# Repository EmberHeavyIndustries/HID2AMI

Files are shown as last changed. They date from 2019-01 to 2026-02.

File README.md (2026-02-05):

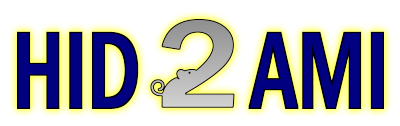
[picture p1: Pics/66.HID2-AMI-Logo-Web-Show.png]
HID2AMI


## ** Preassembled units **: If you are interested in ready-to-go pre-assembled units, a small number of them is available from time to time, assembled by various users/hobbyists. You can look for one on Amibay's thread [link] and check if there is any available on sale (https://www.amibay.com/threads/new-hid2ami-v3-1-0-mousewheel-support-personality-switch-hid-mouse-and-gamepad-to-amiga-adaptor.2451017/) 

|||Email, Contacts & Requests|
| --- | --- | --- |



**HID2AMI** is an **HID mouse to quadrature waveform converter** and **HID Gamepad adapter** for the Amiga (and C64, Atari 7600, AtariST also..) series of boards; it allows ANY modern HID mouse (not limited to PS/2-USB) and almost ANY (*) modern digital/analog Gamepad to be connected and enjoyed with our Amiga computers.

(*) At the moment it has been tested against dozens of different gamepads,  but working for each and every existing Gamepad cannot be guaranteed; nevertheless, if you find a Pad which does not work with HID2AMI, you are encouraged to contact the author and supply him its "HID Report Descriptor" to be investigated.

[HOW TO SUBMIT AN HID DUMP ](https://github.com/EmberHeavyIndustries/HID2AMI/blob/master/Docs/hid.dump.howto.md)

## **ENABLING MOUSEWHEEL SUPPORT**

In order the mousewheel events to be recognized from Amiga side, a proper driver has to be installed on Amiga.

The driver is freely available, and can be downloaded from the FIRMWARE folder on this github
DRIVER

## **REV 3.1 board** 

HID2AMI Rev. 3.1 board (released in February 2025) upgrades previous versions by compacting the size and layout to the tiniest possible, plus adding the capability to switch firmware functions on the fly.

Rev. 3.1.0 comes with the new fromware v4.0.0 which adds the capability to switch among AMIGA - ATARI_ST - C64 behavior, with peculiar features for each.
All V4.x series firmwares will be backward compatible with V2 and V1 boards

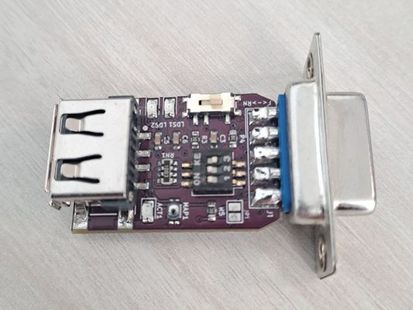
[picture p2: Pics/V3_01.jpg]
Image of HID2AMIV3-01

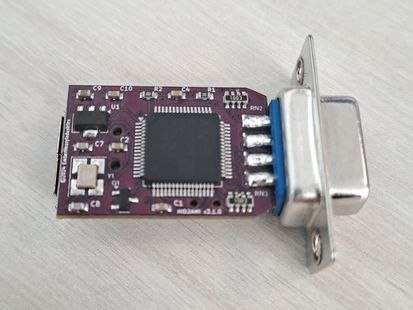
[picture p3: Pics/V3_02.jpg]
Image of HID2AMIV3-02

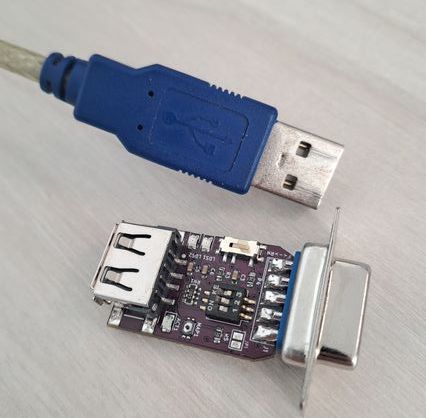
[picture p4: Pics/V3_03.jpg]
Image of HID2AMIV3-03


| Personality | SW1 | SW2  | SW3 | Notes | 
| --- | :---:  | :---:| :---: | --- |
| Amiga | OFF |  OFF | X | Default Classic HID2AMI | 
| Atari ST | ON  |  OFF | X | ST Mouse and Joystick/Joypad |
| C64 | OFF |  ON  | X | C64 Joystick/Joypad with 2nd button |
| CONTROLLER PRIORITY | X  | X  | OFF/ON | J->M->K / K->J->M 	 |

## **Lemaru's shell case (Rev 3.x boards only)** 

Thanks to the talented friend Lemaru, an awesome cover is available for everyone.

You are free to download the stl/step files linked below, and print your own copy of this awesome accessory !

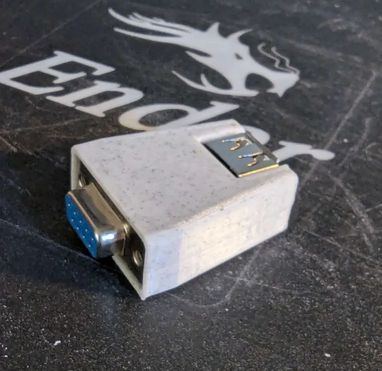
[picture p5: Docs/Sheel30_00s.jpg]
Image of EBOX30-01

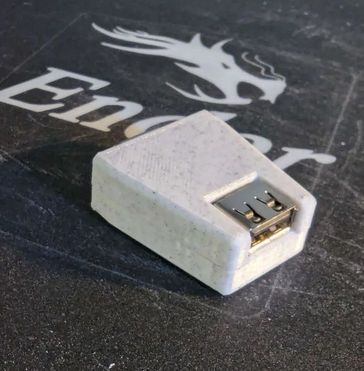
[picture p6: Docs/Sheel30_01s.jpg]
Image of EBOX30-02

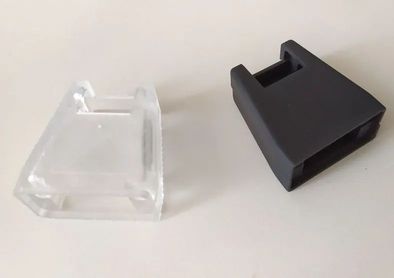
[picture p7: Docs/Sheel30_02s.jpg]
Image of EBOX30-03

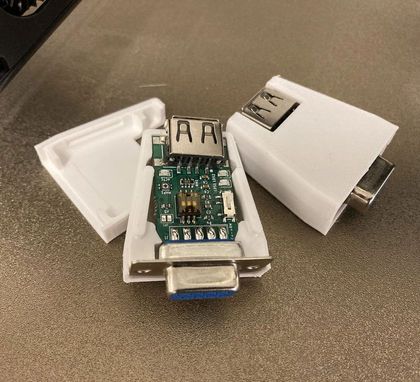
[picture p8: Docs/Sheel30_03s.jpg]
Image of EBOX30-04


[ShellBox30 Top](https://github.com/EmberHeavyIndustries/HID2AMI/blob/master/Docs/HID2AmiV3_Base.stl)

[Shellbox30 Bottom](https://github.com/EmberHeavyIndustries/HID2AMI/blob/master/Docs/HID2AmiV3_Lid.stl)

## **REV 2.0 board** 

HID2AMI Rev. 2.0 board (released in Autumn 2022) upgrades previous versions by adding capability of supporting Mousewheel and CD32 protocols, in a smaller compact shape.

Current firmware v3.0.0 act in the very same way of v1.x.x, with Mousewheel support (CD32 support  will be added in future releases)

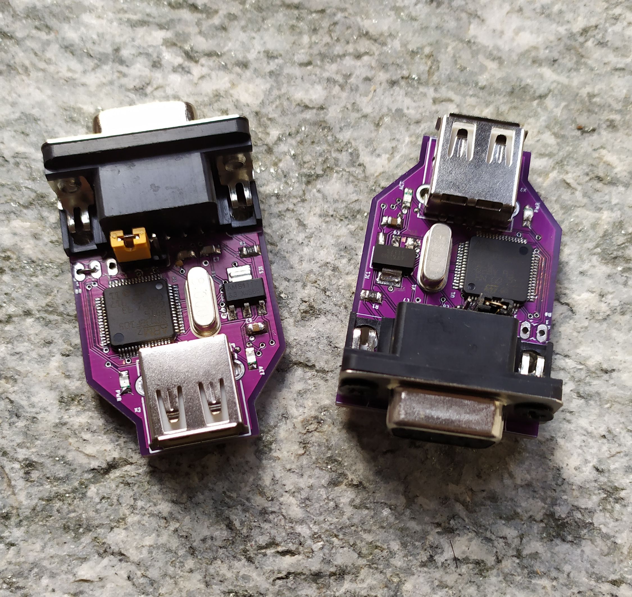
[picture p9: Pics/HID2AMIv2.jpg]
Image of HID2AMI-06
!
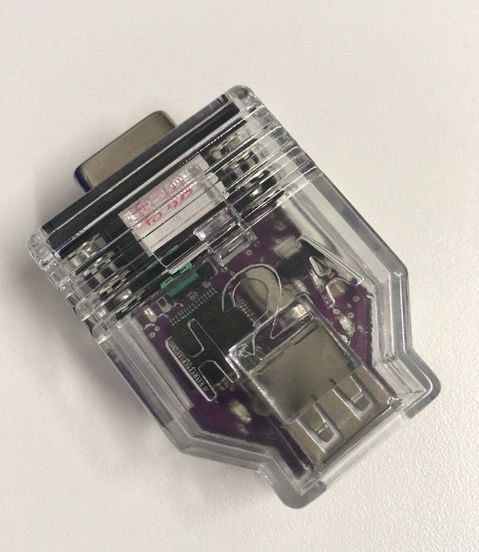
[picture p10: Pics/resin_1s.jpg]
!
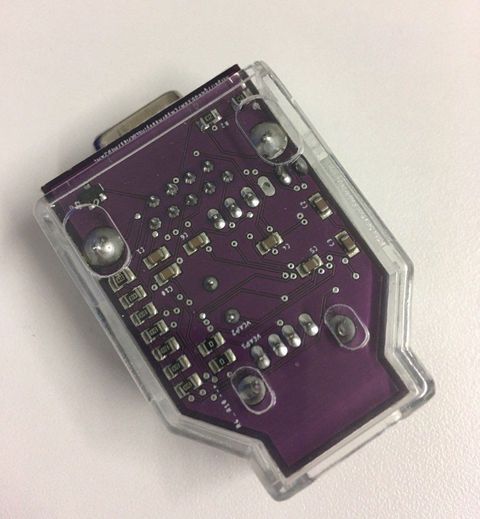
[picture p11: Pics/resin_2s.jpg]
!

(Transparent shellcase images courtesy by IAmAddict)

## **NEW v3.0.0 FIRMWARE WITH MOUSEWHEEL SUPPORT** 

Starting from v3.0.0 firmware, support for mousewheel to ANY adapter hw revision (v1.0, v1.1, V2.0) has been added.

The firmware can be directly flashed on all revisions, and enables native Mousewheel support in v2.0.

In order to enable Mousewheel support on v1.x revisions, a couple of little hacks must be performed on the boards.
The hacks to be performed are: 
- short two adiacent pins of the STM32 microprocessr, by mean of a tiny drop of solder alloy (see pic)
- remove Q2 mosfet and shorten two of the pads (see pic)

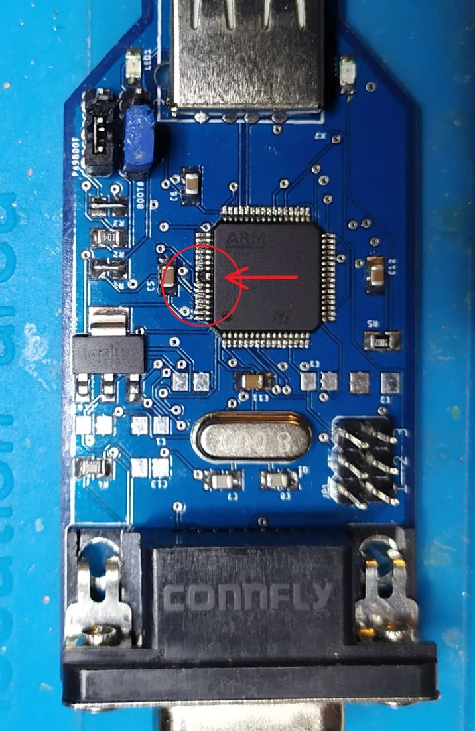
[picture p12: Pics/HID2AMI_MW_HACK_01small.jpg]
HACK01

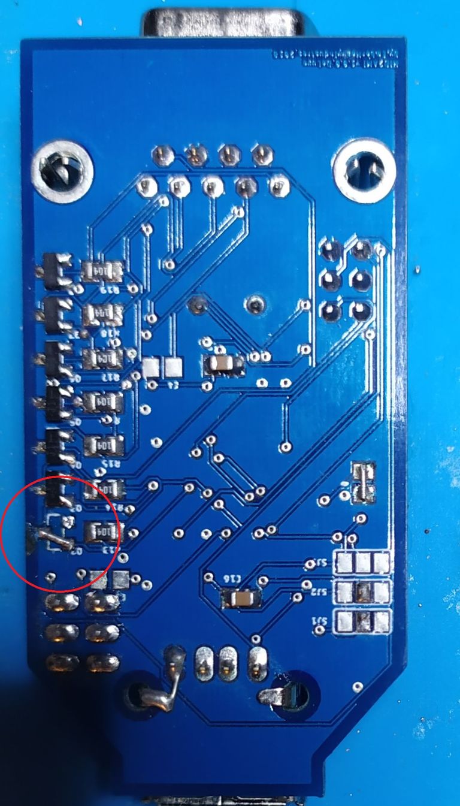
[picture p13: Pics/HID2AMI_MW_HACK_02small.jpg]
HACK02


After the mod, mousewheel works in v1.x all the same way it works in v2.0.
Though the mod is quite trivial, it need a minimal soldering experience.
I cannot be held responsible if anybody damages his board(s) while not properly performing the mod.

In order the mousewheel events to be recognized from Amiga side, a proper driver has to be installed on Amiga.

The driver is freely available, and can be downloaded from the FIRMWARE folder on this github
DRIVER

## **REV 1.1 board** 
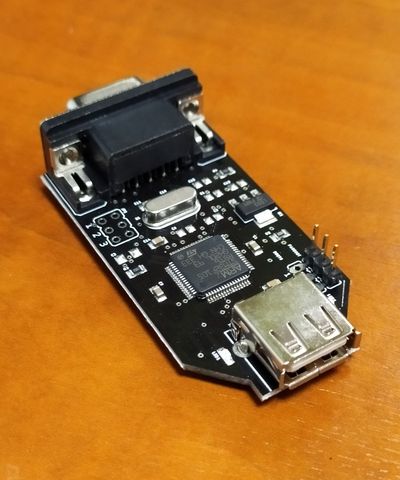
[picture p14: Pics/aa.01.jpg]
Image of HID2AMI-03
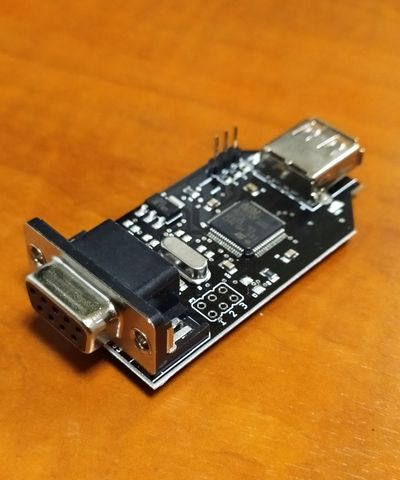
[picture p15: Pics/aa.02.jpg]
Image of HID2AMI-04
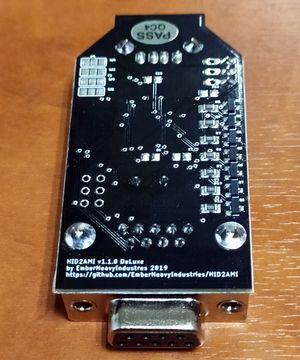
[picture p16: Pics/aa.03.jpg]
Image of HID2AMI-05


## **Ember Heavy Industries's official Open source shell case (Rev 2.x boards only)** 

You are free to download the stl/step files linked below, and print your own copy of this beautiful shell cover !

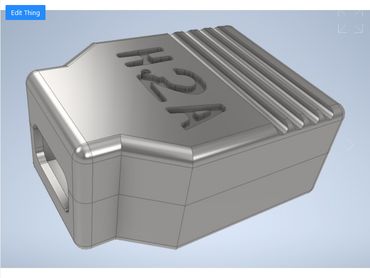
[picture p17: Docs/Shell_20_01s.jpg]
Image of EBOX20-01

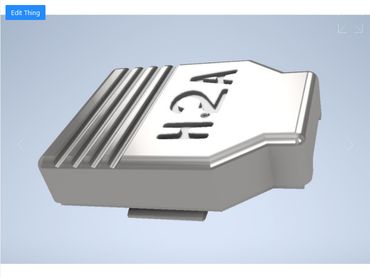
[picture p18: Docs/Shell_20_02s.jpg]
Image of EBOX20-02

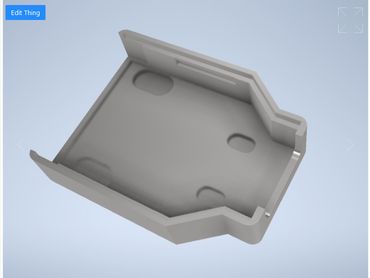
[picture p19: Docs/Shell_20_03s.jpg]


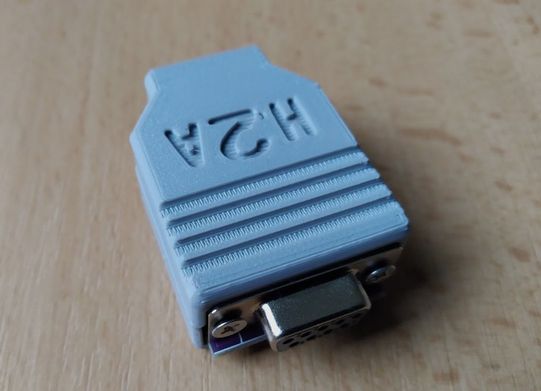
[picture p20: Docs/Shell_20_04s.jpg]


(Sample 3D print by Solaris104)

Image of EBOX20-04
Image of EBOX20-05
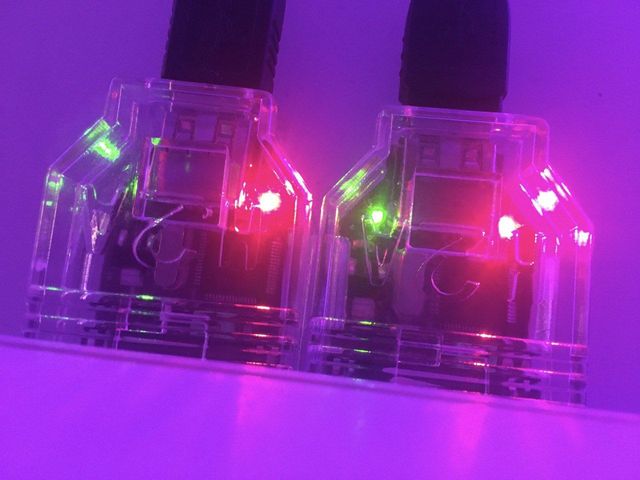
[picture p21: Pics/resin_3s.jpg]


(Sample 3D print by IAmAddicted)

[ShellBox Top](https://github.com/EmberHeavyIndustries/HID2AMI/blob/master/Docs/HID2AMI_ShellUpper.stl)

[Shellbox Bottom](https://github.com/EmberHeavyIndustries/HID2AMI/blob/master/Docs/HID2AMI_ShellLower.stl)

## **CERV's free shell case (Rev 2.x boards only)** 

User Cerv kindly designed and shared his alternative box design !

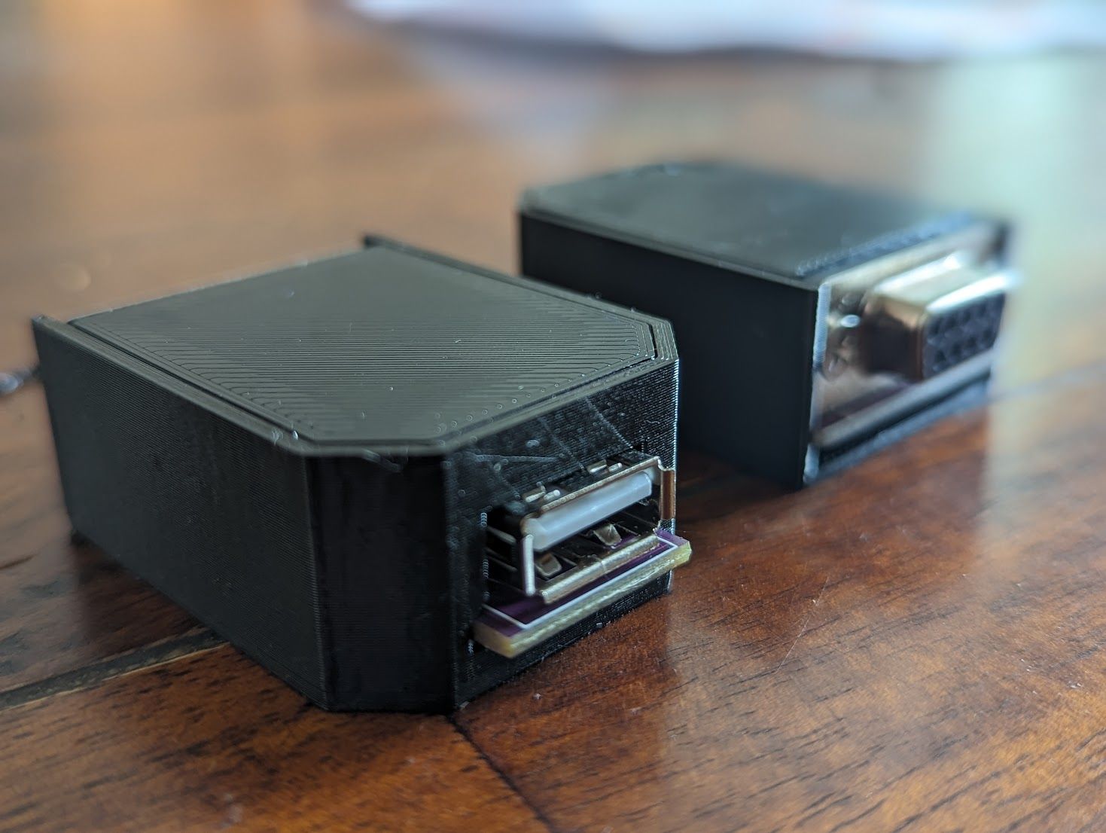
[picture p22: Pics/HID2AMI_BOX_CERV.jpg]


[ShellBox Cover](https://github.com/EmberHeavyIndustries/HID2AMI/blob/master/Docs/HID2AMI_CERV_cover.stl)

[Shellbox Case](https://github.com/EmberHeavyIndustries/HID2AMI/blob/master/Docs/HID2AMI_CERV_box.stl)

## **Ember Heavy Industries's official Open source shell case (Rev 1.1 boards only)** 

#### Based upon Lemaru's shell, with some enhancements and eye-catching HID2AMI logo carved on top  !

You are free to download the stl/step files linked below, and print your own copy of this beautiful shell cover !

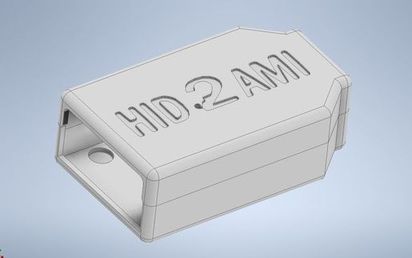
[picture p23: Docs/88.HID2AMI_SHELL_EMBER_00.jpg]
Image of EBOX-01

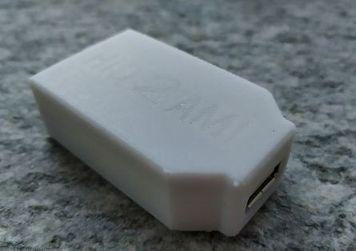
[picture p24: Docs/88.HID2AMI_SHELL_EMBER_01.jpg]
Image of EBOX-02

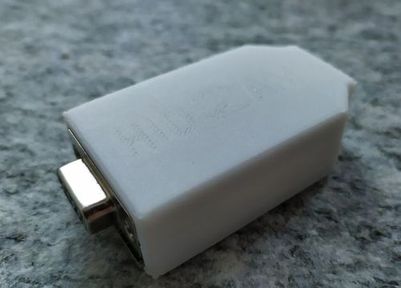
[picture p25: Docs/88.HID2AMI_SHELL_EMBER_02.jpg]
Image of EBOX-03

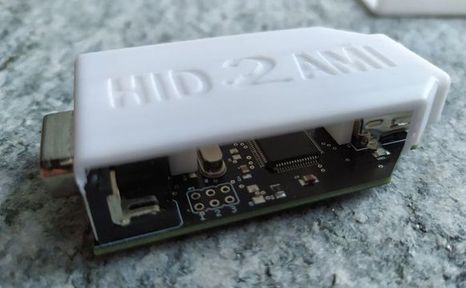
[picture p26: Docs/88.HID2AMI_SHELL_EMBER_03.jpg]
Image of EBOX-04


[ShellBox Top](https://github.com/EmberHeavyIndustries/HID2AMI/blob/master/Docs/88.EmberHID2AMI.UpperShell_1.stl)

[Shellbox Bottom](https://github.com/EmberHeavyIndustries/HID2AMI/blob/master/Docs/88.EmberHID2AMI.LowerShell_1.stl)

## **GothDevil's Open source shell case (Rev 1.1 boards only)** 

#### Thanks to the talented and friendly user **GothDevil** for creating and sharing her precious work  !

You are free to download the stl/step files linked below, and print your own copy of this beautiful shell cover !

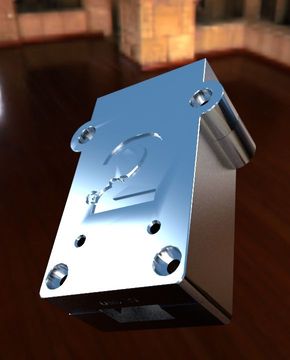
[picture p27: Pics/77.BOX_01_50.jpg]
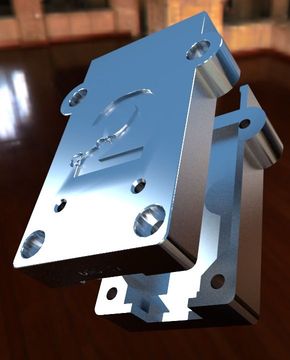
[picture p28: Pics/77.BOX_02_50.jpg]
Image of BOX-02
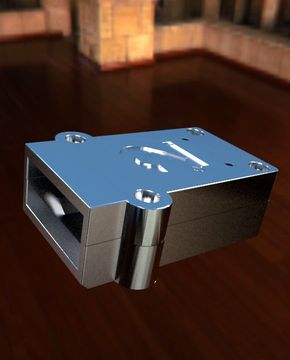
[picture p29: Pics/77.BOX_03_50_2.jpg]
Image of BOX-03


[ShellBox Top](https://github.com/EmberHeavyIndustries/HID2AMI/blob/master/Docs/top_cover_final.stl)

[Shellbox Bottom](https://github.com/EmberHeavyIndustries/HID2AMI/blob/master/Docs/bottom_cover_final.stl)

#### GothDevil kindly allows free and open distribution of this excellent work; nevertheless I (EmberHeavyIndustries) would consider it fair if anyone who enjoys her effort would give her a little donation (say: 1 EUR) to thank her for sharing.
Please send donations to GothDevil's paypal account here:

| ||Thank you GothDevil !|
| --- | --- | --- |

## **Lemaru's Open source shell case (Rev 1.1 boards only)** 

#### Thanks to the talented and friendly user **Lemaru** for creating and sharing his precious work  !
!

You are free to download the stl/step files linked below, and print your own copy of this beautiful shell cover !

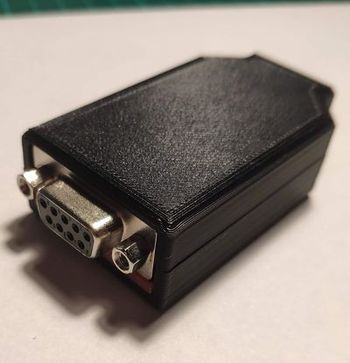
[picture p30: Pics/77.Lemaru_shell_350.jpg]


[ShellBox Top](https://github.com/EmberHeavyIndustries/HID2AMI/blob/master/Docs/HID2AMI_Top.stl)

[Shellbox Bottom](https://github.com/EmberHeavyIndustries/HID2AMI/blob/master/Docs/HID2AMI_Bottom.stl)

## **HOW DOES IT WORK** (in brief):

HID2AMI recognizes and manages any HID device connected to its USB interface; if the device is recognized as an HID mouse, then HID2AMI starts capturing live movements and button pressings of the peripheral, then converting both of them into proper quadrature waveforms (and Amiga mouse button pressings) which can be properly understood by the Amiga itself, as if a real quadrature "Amiga" mouse was connected.

If the device is recognized as an HID gamepad, then HID2AMI maps pad's controls on the Amiga Joystick port/interface.
Gamepad's buttons are mapped evenly on Amiga button1/button2/UP/DOWN (useful for jump & racing games) inputs.
Starting from fw 1.7.1 a custom mapping can be freely configured and stored for automatic retrieval upon reconnection.

There is no need to manually configure the emulation mode: device recognition and operation mode switching are automatically performed by HID2AMI itself.

## **GETTING STARTED AND USER GUIDE**:

Here you can find a quick user guide, describing basic operations and the available meta-commands for peripheral's profile customization, storage and retrieval.

[HID2AMI QUICK USER GUIDE](https://github.com/EmberHeavyIndustries/HID2AMI/blob/master/Docs/Quick.User.Guide.md)

## **COMPATIBILITY LIST**

(!) HID2AMI has been tested against a number of HID compliant Mice and Gamepads; the following compatibility list keeps track of tested peripherals. If you tested your mice/Gamepads and want to contribute to the list, simply send an email to the author with your compatibility results. In case your device is not handled properly, you can submit an HID dump to the author for investigation.  
[HOW TO SUBMIT AN HID DUMP ](https://github.com/EmberHeavyIndustries/HID2AMI/blob/master/Docs/hid.dump.howto.md)

Thanks !

| Device | Model | Min required fw ver. | Working | Notes | |
| --- | ---  |--- | --- | ---| --- |
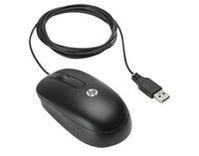
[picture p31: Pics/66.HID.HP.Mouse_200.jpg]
MOU1
| Mice | Any HID Compliant Mouse |  v1.0.0 |  YES | Any HID mouse ||
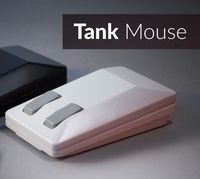
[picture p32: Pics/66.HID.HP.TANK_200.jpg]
MOU66
| Mouse | New USB Tank Mouse |  v1.0.0 |  YES | ||
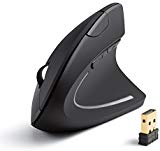
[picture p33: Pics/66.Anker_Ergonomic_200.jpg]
ANKERA
| Mouse | Anker Ergonomic Vertical Mouse |  v1.8.4 |  YES | ||
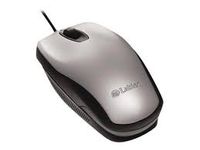
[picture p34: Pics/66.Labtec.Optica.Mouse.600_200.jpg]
MOULA
| Mouse | Labtec Optical Mouse 600 |  v1.8.4 |  YES | ||
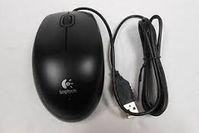
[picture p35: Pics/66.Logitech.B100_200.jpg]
MOUF
| Mouse | Logitech B100 |  v1.0.0 |  YES | ||
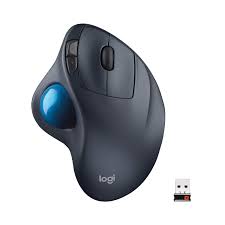
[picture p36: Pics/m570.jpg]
MOUF570
| Mouse | Logitech M570 |  v1.0.0 |  YES | ||
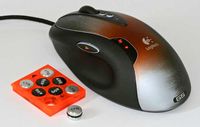
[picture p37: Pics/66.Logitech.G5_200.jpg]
MOU7
| Mouse | Logitech G5 Gaming Mouse |  v1.8.6 |  YES | ||
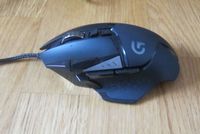
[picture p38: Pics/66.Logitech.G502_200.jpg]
MOU6
| Mouse | Logitech G502 Gaming Mouse |  v1.8.6 |  YES | ||
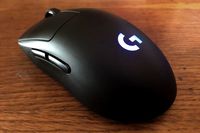
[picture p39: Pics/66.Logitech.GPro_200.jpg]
MOU8
| Mouse | Logitech G Pro Gaming Mouse |  v1.8.6 |  YES | ||
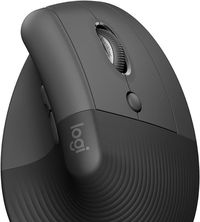
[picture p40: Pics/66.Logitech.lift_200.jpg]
MOU12
| Mouse | Logitech LIFT Vertical Mouse |  v1.8.6 |  YES | ||
| Mouse | Logitech MX510 MX518 G305 G203 G300 G40X G603 G70X G903 RX250 |  v1.8.7 |  YES | |MOUD|
| Mouse | Logitech M-BT83 Wired Mouse |  v1.9.2 |  YES | |MOULO2|
| Mouse | Logitech Performance MX BT |  v1.8.7 |  YES | |MOU10|
| Mouse | Logitech Wireless Mouse M220, M305, M560, M70X |  v1.7.4 |  YES | |MOU3|
| Mouse | Logitech Wireless Mouse M590 |  v1.8.4 |  YES | |MOU4|
| Mouse | Logitech Wireless Mouse Mx Master  |  v1.8.4 |  YES | |MOUD|
| Mouse | Microsoft Classic Intellimouse 2018|  v1.8.c |  YES | |MOUCL| 
| Mouse | Microsoft Intellimouse |  v1.6.0 |  YES | Not 100% HID protocol compliant |MOU2| 
| Mouse | Microsoft Intellimouse Explorer |  v1.8.4 |  YES | Wireless explorer series |MOU5|
| Mouse | Microsoft Wireless Laser 6000, 7000|  v1.8.4 |  YES | Wireless explorer series |MOUD|
| Mouse | Rapoo 7100P  Wireless Mouse |  v1.8.6 |  YES | |MOUE|
| Mouse | Steelseries Rival 100 and 110 |  v1.8.6 |  YES | |MOU9|
| Mouse | Steelseries Rival 310 |  v1.8.6 |  YES | |MOUA|
| Mouse | Steelseries Rival 500 |  v1.8.6 |  YES | |MOUB|
| Mouse | Steelseries Rival 600 |  v1.8.7 |  YES | |MOUC|
| Mouse | Targus Mini Mouse |  v1.7.4 |  YES | Not 100% HID protocol compliant |MOU4|
| Mouse | Trust Wireless 18519 YVI |  v1.8.8 |  YES | |MOU11|
| Mouse | Yenkee YMS 3007 |  v1.8.4 |  YES | |MOULY|
| Gamepad | 8bitd0 SFC30 Bluetooth |  v1.8.0 |  YES | |(BITD=|
| Gamepad | 8bitd0 M30 Wireless 2.4G |  v1.8.0 |  YES | |(BITE=|
| Adapter | 8bitd0 Wireless adapter 2.4G |  v1.8.0 |  YES | All wireless controllers (xbox ONE, etc) |(BITF=|
| Joystick | Arcade Stick w/ USB encoder |  v1.3.0 |  YES | Stick is digital only |ARC1|
| Joystick | C64 Mini Stick |  v1.3.0 |  YES | Stick is digital only |C641|
| Gamepad | Diswoe Wireless PC/Nintendo Switch |  v1.8.0 |  YES | |(DISW=|
| Gamepad | Dual Stick China Clone |  v1.3.0 |  YES | Both digital and analog mode |CHN1|
| Gamepad | Dual Wireless PS3-USB or BT |  v1.9.8 |  YES | Both digital and analog mode  (3) |CHN2|
| Gamepad | Hama Whitestorm |  v1.3.0 |  YES | Both digital and analog mode |HAM1|
| Joystick | HORI FightingStick Mini |  v1.8.0 |  YES | Both PS3 and PS4 mode |HFS1|
| Gamepad | Logitech PS2 Wireless |  v1.3.0 |  YES | Both digital and analog mode |WPS2|
| Gamepad | Logitech Rumble Gamepad F310 |  v1.6.0 |  YES | Both PC and XBOX 360 mode |WRP5|
| Gamepad | Logitech Rumble Gamepad F510 |  v1.6.0 |  YES | Both PC and XBOX 360 mode |WRP3|
| Gamepad | Logitech Rumblepad 2 |  v1.3.0 |  YES | Both digital and analog mode |WRP1|
| Gamepad | Logitech Wingman Rumblepad |  v1.3.0 |  YES | Both digital and analog mode |WRP2|
| Gamepad | Logitech Wireless Gamepad F710 |  v1.8.0 |  YES | Both PC and XBOX 360 mode |WRP4|
| Gamepad | PS3/PC Clones |  v1.5.2 |  YES | Both digital and analog mode |PS3CLONE|
| Gamepad | RetroLink Classic Controller USB |  v1.8.0 |  YES | (Sega Saturn Style) |SEGASAT|
| Gamepad | SEGA Mega Drive Mini USB Pad |  v1.9.1 |  YES | |SEG2|
| Joystick | SEGA VirtuaStick High Grade |  v1.8.0 |  YES | PS3 mode - Stick is digital only |SEG1|
| Gamepad | Sony PS1 original pad |  v1.6.0 |  YES | With USB adapter |THFS3|
| Gamepad | Sony PS2 original pad |  v1.6.0 |  YES | With USB adapter |THFS5|
| Gamepad | Sony PS2 original pad |  v1.8.1 |  YES | With DUAL USB adapter (1) |THFS7|
| Gamepad | Sony PS-ONE original pad |  v1.6.0 |  YES | With USB adapter |THFS6|
| Gamepad | Sony Dual Shock 3 PS3 original pad |  v1.8.b |  YES | With USB cable or BT **WARNING !! (2) (3)**  |SDS5|
| Gamepad | Sony Dual Shock 4 PS4 original pad |  v1.8.0 |  YES | **WARNING !! (2)** |SDS4|
| Gamepad | SNES Usb Clone |  v1.3.0 |  YES | Pad is digital only |THFS4|
| Joystick | Speedlink Competition PRO USB |  v1.8.0 |  YES | |SLNK1|
| Gamepad | Speedlink TORID WL			 |  v1.8.0 |  YES | Put in XInput mode |SLNK2|
| Gamepad | Thrustmaster Firestorm Digital |  v1.3.0 |  YES | Pad is digital only |THFS2|
| Joystick | Thrustmaster T-16000M |  v1.8.0 |  YES | |(THT16=|
| Gamepad | Thrustmaster Wireless dual trigger |  v1.3.0 |  YES | Both digital and analog mode |THWD|
| Gamepad | XBOX 360 Clone |  v1.6.0 |  YES | Not HID protocol compliant |XBOX 
| Gamepad | XBOX Elite |  v1.8.0 |  YES (*) |(*) works via 8bitdo Wireless dongle |XBOXE
 
 (1) Plug the pad in adaptor #1 port
 
 (2) **WARNING! If using the wired version, either remove internal battery (suggested) or be sure it is 100% charged before connecting to your Amiga**
 
 (3) Click d-pad (Hat) soon after connection to start auto-reconfiguration of the pad

 ## **HW AND SCHEMATICS**
  
| Flavour | Current ver.  | Features |
| --- | --- | --- |
| HID2AMI LITE | v1.0.0 | direct output to Amiga port lines |
| HID2AMI DeLuxe | v1.1.0 | output lines driven by mosfet |
| HID2AMI DeLuxe | v2.0.0 | compact size, reduced mosfets |

## **FIRMWARE**
  
| Baseline 		| Current ver.  | Features |
| --- 		| --- | ---|
| HID2AMI BOOTLOADER 		| v1.4.0 | Enables DFU upgrade of APP |
| HID2AMI OEM BOOTLOADER 	| v1.4.0 | Enables DFU upgrade of APP |
| HID2AMI APP 		| v4.0.3 	| see release notes below |

Features of fw v4.04
 - Fixed further line driving in ODmode for "weak" C64 consoles [no more "locked last keyb row"]
 - Added gaming numpad support [SWOS edition] 
 - Extended keyboard decoding up to three keys at the same time [SWOS edition]
 - Denied conflicting direction with keyb (L+R and U+D) [SWOS eidiotn - fix for Amiga orignal SWOS game's bug]
 - Added forcing Razer DeathStalker V2 to Keyboard [SWOS edition]
 - Added support for Shenzhen Evision Semiconductor Technology Wireless adapter for Mouse (Aliexpress)
 - Added priority input selector for multi-device-cntrollers (default priority is Joy->Mouse->Keyboard, alternate is Keyboard->Joy->Mouse)

| Personality | SW1 | SW2  | SW3 | Notes | 
| --- | :---:  | :---:| :---: | --- |
| Amiga | OFF |  OFF | X | Default Classic HID2AMI | 
| Atari ST | ON  |  OFF | X | ST Mouse and Joystick/Joypad |
| C64 | OFF |  ON  | X | C64 Joystick/Joypad with 2nd button |
| CONTROLLER PRIORITY | X  | X  | OFF/ON | J->M->K / K->J->M 	 |

Features of fw v4.03
 - Added customizable keyboard mapping (SWOS edition)
 - Fixed C64 mode keyb conflict
 - Fixed Mouse scroll down not working in some PiStormed A1200

Features of fw v4.0.2
-	SWOS edition
-	Enabled USB keyboard support

Features of fw v4.0.1
 - 	Added Razer Steel Series Rival 3 Mouse support

Features of fw v4.0.0
 - 	HRW v3.x support - full backward compatibility with v2.x and v1.x (v1.x need scrollwheel hw hack)
 - 	HRW v3.x personality mode switch AMIGA-ATARI-C64
   
| Personality |  Switch position 0 1 2 | Notes |
| --- | --- |--- |
| Amiga | OFF OFF OFF | Default Classic HID2AMI | 
| Atari ST | ON OFF OFF | ST Mouse and Joystick/Joypad |
| C64 | OFF ON OFF | C64 Joystick/Joypad with 2nd button |

Features of fw v3.0.5
 - 	Added flash storage for PS4 controllers mapping
 - 	Added Logitech VX Nano support
 - 	Added Logitech G403 Hero support
 - 	Added Advanced Corded Mouse M500s support
 - 	All Logitech wireless dongles default to mouse

Features of fw v3.0.4
 - Fixed an elusive bug that activated the multiplier setup mode each time the power was turned back on
 - Fixed a bug where changing mouse pointer direction after a stop. Mouse movements are now pixel perfect

Features of fw v3.0.3
 - Maintenance release
   
Features of fw v3.0.2
 - Added support for Logitech G602, G9x, G700
 - Added support for Razer DeathAdder 2013
 - Added support for Dell Wireless Mouse (from set KM3322W)
 - Added support for X8 mouse speed demultiplier (1000dpi + mice)
 - Added support for "Mad Catz" Speedlink competition pro

Features of fw v3.0.1
 - Enabled management of 3rd mouse button in conjunction with MouseWheel
 
Features of fw v3.0.0
 - Unified firmware for all HID2Ami revisions, compatible with v1.0, v1.1, v2.0
 - Add mousewheel support on all Amigas (V2.0)
 - Add mousewheel support with v1.x boards + hw fix
 
Features of fw v1.9.8
 - Added support for Microsoft Wireless Mobile Mouse 4000
 - Added support for Logitech MX Revolution Mouse
 - Added support for Logitecg G400 Gaming Mouse
 - Added support for Logitech G700 Laser Mouse
 - Added support for Logitexh MX Master 3S
 - Added support for PS3 DualShock3 BT adapter plus coded trick to detect USB o BT connection (move hat soon after connecting)
 - Fixed deadzone values for XBOX360 pads

Features of fw v1.9.7:
 - Added full mapping support for XBox360 and compatible pads
 
Features of fw v1.9.6:
 - Added support for cursor arrow keys in keyboard driver
 - Joypad buttons now can be mapped either B1-B2-UP-DN or B1-B2-B1-B2 (the latter by pressing LEFT direction while mapping) 
 - Added MS Touch Wireless Mouse support
 - Added MS BTechnology wireless adapter
 - Fixed a custom HID mouse protocol init bug (greatly improves compatiiblity with non standard HID devices) 

Features of fw v1.9.5:
 - Added support for Logitech B170 / M170 wireless adapters and peripherals
 - Added generic support for composite (multi-peripheral) Logitech devices
	
Features of fw v1.9.4:
 - Fixed a very stupid bug, which caused quadrature waveform emulation non behaving correctly.
        Though anybody noticed it (not even myself until now !), the fixed quadrature waveform now performs
        way smoother pointer movements. 
	
Features of fw v1.9.3:
  - Added support for SpeedLink Competition Pro USB 2019+
  - Fixed a stupid bug not clearing device mapping upon disconnection (very hardly to occur, indeed)
 
Features of fw v1.9.2:
  - Added support for Logitech M-BT83 Wired Mouse 
   
Features of fw v1.9.1:
  - Added support for SEGA Mega Drive Mini USB Adapters 

Features of fw v1.9.0:
  - Added support for HID keyboards with "WADS" mapping 

Features of fw v1.8.c:
  - Added support for Microsoft Classic Intellimouse 2018 

Features of fw v1.8.b:
  - Added support for Sony PS3 Dualshock3 PAD

Features of fw v1.8.a:
  - Fixed a stupid bug which prevented 16-bit-axis mice to be correctly managed

Features of fw v1.8.9:
 - Changed mousewheel behaviour: 
   - 1. Defaults to no action [hint: probably adding freemouse support in one of next updates]
   - 2. Pressing all three mouse buttons together, board enters "pointer speed setting" mode [Led stops blinking->firmly lit]
   - 3. Rolling Mousewheel now changes pointer speed / DPI sensitivity
   - 4. Pressing all three button together again will save current setting and return to default behaviour [Led starts blinking again]
 - Added support for Logitech MK250
 - Added support for RAPOO 5G Wireless Mouse
 - Added support for ATARI ST Mouse port (ALL devices)
 
Features of fw v1.8.8:
- Added support for Trust IVY 18519 Wireless Mouse
- Added support for Logitech M305 BT Wireless Mouse

Features of fw v1.8.7:
- Added support for Logitech MX510 MX518 G305 G203 G403 G603 G703 G903 gaming mice
- Added support for SteelSeriec Rival 110 and 600 Gaming mice
 
Features of fw v1.8.6:
- Added support for Logitech G502, G5 and G Pro Gaming mice
- Added support for SteelSeriec Rival 100, 310 and 500 Gaming mice

Features of fw v1.8.5:
- Added automatic recognition and management of hw customized report Id (improves compatibility)

Features of fw v1.8.0:
- Added support for PS3 and PS4 3rd party compatible pads 
- Added support for original Dual Shock 4 PS4 pads
- Reworked 12-bit XY axis support for gaming/precision mice
- Improved compatibility with some Logitech gaming mice

Features of fw v1.7.4:
- Added support for Logitech M560 Wireless Mouse
- 	Added support for Targus MiniMouse
- 	Added multiple HID device interface support (greatly improves compatibility)
-	Added preliminary Microsoft Wireless Laser Mouse 6000 support
- Added preliminary support to XBOX ONE gamepads

Features of fw v1.7.3:
- Added custom free mapping of first 4 buttons of Gamepad. By pressing 4buttons+LeftStickDown the board enters in mapping mode; pressing in turn single buttons maps them on Amiga1->Amiga2->Up->Down
- Added custom mapping config autosave: each custom configuration is permanently stored and recalled upon Gamepad reconnection.
- Separate permanent configs (up to 20) are saved and recalled automatically upon recognition of Gamepads brand/model
- Added support for 12 bit high resolution gaming mice
- Added customizable real-time mouse pointer speed adjust, by rolling the mousewheel forward/backwards
- Added save of permanent config for mouse pointer speed, by pressing L-M-R buttons together 

Features of fw v1.7.1:
- Added mapping of DWN/backward to Gamepad 4th button. Buttons are now evenly mapped according P1->P2->UP->DWN sequence;
- User can swap UP<->DWN button mapping by simultaneously pressing first 4 pad's buttons;

Features of fw v1.6.2:
- Added mapping of UP/Forward to Gamepad 3rd button;
- Optimized gamepad decoding core, even faster response;

Features of fw v1.6.0:
- Added support for XBOX 360 Gamepad clones;
- Added support for MS Intellimouse;

Features of fw v1.5.2: 
- Unified firmware, self configuring according to board variant (Lite or DeLuxe);
- Automatic recognition of any HID mouse;
- Automatic recognition of any (!) HID joystick/gamepad;
- Full support for both USB 1.1 and USB 2.0 periperhals;
- Support for both digital (hatswitch) and analog x-y gamepad axis;
- Automatic emulation mode switch upon peripheral connection (no need of any manual settings);
- Self discover and mapping of pad buttons (limited to first 6);
- Easy firmware upgrade through (windows) PC USB interface;

## **READ CAREFULLY BEFORE CONNECTING ANY PAD/MOUSE TO YOUR AMIGA**

 **BE AWARE** that when you connect a peripheral to the Amiga's mouse/joy port, the power supply or that peripheral comes from/through that port itself. **Be aware that improperly connecting an "high" power-demanding device could lead to overheat or even damage the Amiga joy/mouse port**. 

If you connect controllers with rechargeable batteries, **be absolutely confident that the battery has been fully charged**  **BEFORE** connecting it to the Amiga, or the charging current flowing from the joy/mouse port to your controller's battery could seriosly damage your Commodore  !

 You are usign HID2AMI at your own risk: I will either not be liable nor responsible for any damage you could cause to your hardware for any use or misuse of HID2AMI together with your systems.  

## **DEVELOPMENT**

HID2AMI hardware and firmware were designed, developed and maintained by **Sampedenawa** on behalf of **EmberHeavyIndustries** (an evil worldwide company, whose mission is to rule the world by the mean of reviving Amiga computers), following a discussion born on Italian www.amigapage.it Amiga forum.

## **ASSEMBLY**

 ## **WARNING !!  A COUPLE THINGS YOU MUST UNDERSTAND BEFORE GOING FURTHER**
 
 - **NEVER, NEVER, NEVER connect "both sides" of HID2AMI to a power source at the same time !**
 **This means: do not connect HID2AMI to a PC through the USB port while it is plugged into your Amiga's joy/mouse port !**
 **If you want to upgrade your HID2AMI with bootloader or DFU mode, beware to disconnect it from your Amiga first !**
 
 - **BE AWARE** that when you connect a peripheral to the Amiga's mouse/joy port, the power supply or that peripheral comes from/through that port itself. Amiga control peripheral ports were probably not designed with "mega-rumble-end-of-universe-nuclear-powered" gamepads in mind: while there is generally no risk in connecting "common" mainstream peripherals like the ones have been tested (see above), be aware that improperly connecting an "high" power-demanding device could lead to overheat or even damage the Amiga joy/mouse port. **You can consider the power consumption safety limit roughly around 100mA; exceeding this limit could be dangerous for your Amiga!.** 
 
 ## **You are using HID2AMI at your own risk: I will either not be liable nor responsible for any damage you could cause to your hardware for any use or misuse of HID2AMI together with your systems.**  

#### Starting from scratch
 - Get latest gerber files available and build the pcb with a service of your choice
 - Get the BOM and buy all needed components
 - Assemble your board (moderate soldering skills needed)
 - Put the board in DFU mode and upload bootloader (USB A-A cable, DFU drivers and a Windows PC needed) *(a)*
 - Put the board in BOOTLOADER mode, get your personal board-license-unique-code
 - Get the HID2AMI APP from the author, by sending him a request together with your board-license-unique-code
 - Put the board in BOOTLOADER mode and upload the APP *(b)*
 - Put the board in APP mode
 - Plug in and enjoy !
 
#### DIY KIT
 - Assemble your board (moderate soldering skills needed)
 - Put the board in DFU mode and upload bootloader (USB A-A cable, DFU drivers and a Windows PC needed) *(a)*
 - Put the board in BOOTLOADER mode, get your personal board-license-unique-code
 - Get the HID2AMI APP from the author, by sending him a request together with your board-license-unique-code
 - Put the board in BOOTLOADER mode and upload the APP *(a)*
 - Put the board in APP mode
 - Plug in and enjoy !
  
  *(a) The bootloader need to be flashed only once in each HID2AMI's board lifetime*
  
  *(b) The HID2AMI APP can be flashed at any new firmware release*
  
#### PREASSEMBLED BOARD
 - Just plug in and enjoy !

### ASSEMBLING REFERENCE DOCS

At first, look at a fully assembled board (please note some vacancies: not all pads shall be populated)

[Reference Board: TOP](https://github.com/EmberHeavyIndustries/HID2AMI/blob/master/Pics/HID2AMI.Black.Top.jpg "Reference Board: TOP")

[Reference Board: BOTTOM](https://github.com/EmberHeavyIndustries/HID2AMI/blob/master/Pics/HID2AMI.Black.Bottom.jpg "Reference Board: BOTTOM")

#### **SCHEMATICS**

[HID2AMI v1.0.0 SCHEMATICS SHEET](https://github.com/EmberHeavyIndustries/HID2AMI/blob/master/Board/HID2AMI.Deluxe.Rev1.0.0.redist.sch)

[HID2AMI v1.1.0 SCHEMATICS SHEET](https://github.com/EmberHeavyIndustries/HID2AMI/blob/master/Board/HID2AMI.Deluxe.Rev1.1.0.redist.sch)

[HID2AMI v2.0.0 SCHEMATICS SHEET](https://github.com/EmberHeavyIndustries/HID2AMI/blob/master/Board/HID2AMI.Deluxe.Rev2.0.0.sch)

#### **REFERENCE LAYOUTS**

[Reference Layout v1.0.0 Top](https://github.com/EmberHeavyIndustries/HID2AMI/blob/master/Board/HID2AMI.Deluxe.Rev1.0.0.redist.layout.top.pdf)

[Reference Layout v1.0.0 Bottom](https://github.com/EmberHeavyIndustries/HID2AMI/blob/master/Board/HID2AMI.Deluxe.Rev1.0.0.redist.layout.bottom.pdf)

[Reference Layout v1.1.0 Top](https://github.com/EmberHeavyIndustries/HID2AMI/blob/master/Board/HID2AMI.Deluxe.Rev1.1.0.layout.top.pdf)

[Reference Layout v1.1.0 Bottom](https://github.com/EmberHeavyIndustries/HID2AMI/blob/master/Board/HID2AMI.Deluxe.Rev1.1.0.layout.bottom.pdf)

#### **BILL OF MATERIALS**

Components noted as "Optional" fulfil the general purpose STM32F1x reference design; generally speaking they can be safely omitted from the assembly of HID2AMI. Consider soldering any of them in case you experience some instability of any kind (never experienced so far).

LED1 is "run mode" indicator; it blinks at variable rates to indicate HID2AMI running status (suggesetd colors: green, yellow, white)
- When in BOOTLOADER mode, a fast blink means bootloader running and waiting for the "App" to be flashed/upgraded
- When in APP mode, a "regular" blinking means the App is running and waiting for input; a slower blinking (upon connecting a peripheral), means the peripheral correctly identified and mapped 

LED2 is the "power on" indicator; if lit then your board gets correct +5V and +3.3V power supply 

For both LED1 and LED2, the suggested value for their respective limiting current resistors is 10k, but you can safely experiment any value in range 1k-47k depending on the led components characteristics and light efficiency (and your personal taste)

[Reference BOM v1.0.0](https://github.com/EmberHeavyIndustries/HID2AMI/blob/master/Board/HID2AMI.Deluxe.Rev1.0.0.BOM.txt)

[Reference BOM v1.1.0](https://github.com/EmberHeavyIndustries/HID2AMI/blob/master/Board/HID2AMI.Deluxe.Rev1.1.0.BOM.txt)

[Reference BOM v2.0.0](https://github.com/EmberHeavyIndustries/HID2AMI/blob/master/Board/HID2AMI.Deluxe.Rev2.0.0_BOM.txt)

[Reference BOM v3.1.0](https://github.com/EmberHeavyIndustries/HID2AMI/blob/master/Board/HID2AMI.Deluxe.Rev3.1.0_BOM.csv)

### **GERBER FILES**

[HID2AMI v1.0.0 DELUXE GERBER FILES](https://github.com/EmberHeavyIndustries/HID2AMI/blob/master/Board/HID2AMI.Deluxe.Rev1.0.0.redist_2019-01-19.zip)

[HID2AMI v1.1.0 DELUXE GERBER FILES](https://github.com/EmberHeavyIndustries/HID2AMI/blob/master/Board/HID2AMI.Deluxe.Rev1.1.0.redist_2019-02-28.zip)

[HID2AMI v2.0.0 DELUXE GERBER FILES](https://github.com/EmberHeavyIndustries/HID2AMI/blob/master/Board/HID2AMI.Deluxe.Rev2.0.0_2021-09-24.zip)

[HID2AMI v3.1.0 DELUXE GERBER FILES](https://github.com/EmberHeavyIndustries/HID2AMI/blob/master/Board/HID2AMI.Deluxe.Rev3.1.0.zip)

### **EAGLE SCHEMATICS AND BOARD LAYOUT**

[HID2AMI v1.0.0 DELUXE SCHEMATICS](https://github.com/EmberHeavyIndustries/HID2AMI/blob/master/Board/HID2AMI.Deluxe.Rev1.0.0.redist.sch)

[HID2AMI v1.0.0 DELUXE BRD](https://github.com/EmberHeavyIndustries/HID2AMI/blob/master/Board/HID2AMI.Deluxe.Rev1.0.0.redist.brd)

[HID2AMI v1.1.0 DELUXE SCHEMATICS](https://github.com/EmberHeavyIndustries/HID2AMI/blob/master/Board/HID2AMI.Deluxe.Rev1.1.0.redist.sch)

[HID2AMI v1.1.0 DELUXE BRD](https://github.com/EmberHeavyIndustries/HID2AMI/blob/master/Board/HID2AMI.Deluxe.Rev1.1.0.redist.brd)

[HID2AMI v2.0.0 DELUXE SCHEMATICS](https://github.com/EmberHeavyIndustries/HID2AMI/blob/master/Board/HID2AMI.Deluxe.Rev2.0.0.sch)

[HID2AMI v2.0.0 DELUXE BRD](https://github.com/EmberHeavyIndustries/HID2AMI/blob/master/Board/HID2AMI.Deluxe.Rev2.0.0.brd)

### **BOOTLOADER**

Current BOOTLOADER version is 1.4.0. You can freely get it from here [HID2AMIBOOTLOADER](https://github.com/EmberHeavyIndustries/HID2AMI/blob/master/Firmware/HID2AMIBOOTLOADER.dfu)

### **FLASHING INSTRUCTIONS**

Detailed flashing instructions, and how to get your personal HID2AMI board code, can be found here, for both Linux (courtesy by Sukkopera) and Windows:

[HID2AMI FLASHING INSTRUCTIONS](https://github.com/EmberHeavyIndustries/HID2AMI/blob/master/Docs/Flashing.Instructions.md)

## **LICENSE TERMS**


### **Schematics and pcb gerbers**
of HID2AMI are open source, released under the Creative Commons CC BY-NC license.
This means that you are free to:

| | |
| --- | --- |
| SHARE | copy and redistribute the material in any medium or format |
| ADAPT | remix, transform, and build upon the material |

Under the following terms:

| | |
| --- | --- |
| Attribution | You must give appropriate credit, provide a link to the license, and indicate if changes were made. You may do so in any reasonable manner, but not in any way that suggests the licensor endorses you or your use. |
| NonCommercial | You may not use the material for commercial purposes. |
| ShareAlike | If you remix, transform, or build upon the material, you must distribute your contributions under the same license as the original. |
| No additional restrict| You may not apply legal terms or technological measures that legally restrict others from doing anything the license permits.  |

### **HID2AMI BOOTLOADER** 
is free to download, copy and redistribuite.

### **HID2AMI APP** 
is distribuited by request, after a minmum donation to support the development, from the author; each instance is strictly tied 1:1 to a particular HID2AMI board. You are not allowed to copy and distribuite HID2AMI APP in any medium or format. 

## **DISTRIBUTION AND PRICING POLICY**
I've spent a great effort in designing and developing this app, so I would be grateful if you'd be happy to contibute to its future development. I decided to release all project's details, schematics and gerbers for free to everyone, but retaining myself close control over the firmware app. Being this one a no-profit hobbyist project, I can't guarantee any volume production of boards, so I will following the following distributio policies, for who may be interested in having one:

- Software only
  - You build the board yourself, by mean of the public gerbers or by a compatible custom layout you derive from schematics
  - You get the APP from me by sending me a request together with your personal 4-digits code (see instructiuons above how to get it)
  - Availability to serve request and cost of the app shall be exposed here or on the Amiga Forums I (Sampedenawa) am frequenting. Find HID2AMI on [Amigapage](http://www.amigapage.it), [EAB](https://eab.abime.net), [A1K](https://www.a1k.org). 

- DYI KIT
  - You build the board yourself by getting from me the pcb and all needed components
  - You get the APP from me by sending me a request together with your personal 4-digits code 
  - Availability and costs of DIY kits shall be exposed here or on the Amiga Forums I (Sampedenawa) am frequenting. Find HID2AMI on [Amigapage](http://www.amigapage.it), [EAB](https://eab.abime.net), [A1K](https://www.a1k.org).

- COMPLETE BOARD
  - You get the fully working board from me by sending me a request 
  - (Rare) Availability and costs of complete boards shall be exposed here or on the Amiga Forums I (Sampedenawa) am frequenting
. Find HID2AMI on [Amigapage](http://www.amigapage.it), [EAB](https://eab.abime.net), [A1K](https://www.a1k.org).

## **Warranty Disclaimer and Limitation of Liability**

HID2AMI is an hobbyist project without any commercial intention; you understand that we cannot and do not guarantee or warrant neither the HID2AMI hardware (including but not limited to: schematics, gerbers, pcb, components, assembling, etc.) nor the HID2AMI software (bootloader, app, etc) from defects, breakage or loss of functionality. You are using HID2AMI under your exclusive risk and responsibility; please understand and AGREE that **WE WILL NOT BE LIABLE FOR ANY LOSS OR DAMAGE CAUSED BY EITHER ANY USE OR ANY MISUSE OF HID2AMI**

BY MAKING USE OF HID2AMI, YOU EXPRESSLY AGREE THAT YOUR WILL ACCEPT IT ON "AS IS" BASIS WITHOUT ANY WARRANTIES OF ANY KIND, EITHER EXPRESS OR IMPLIED. YOU ALSO EXPRESSELY AGREE THAT YOUR USE OF HID2AMI HARDWARE AND ITS SOFTWARE COMPONENTS IS AT YOUR OWN RISK. NEITHER THE AUTHOR (Sampedenawa) NOR ANY PERSON ASSOCIATED WITH THE AUTHOR MAKES ANY WARRANTY OR REPRESENTATION WITH RESPECT TO THE COMPLETENESS, SECURITY, RELIABILITY, QUALITY, ACCURACY OR AVAILABILITY OF THE HID2AMI HARDWARE/SOFTWARE.

IF YOU DO NOT UNDERSTAND AND EXPRESSLY AGREE WHAT STATED ABOVE, YOU ARE NOT ENTITLED BY THE AUTHOR TO USE HID2AMI FOR ANY PURPOSE.

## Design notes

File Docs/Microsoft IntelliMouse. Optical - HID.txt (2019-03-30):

Connection Status Device connected 
Current Configuration 1 
Speed Full (12 Mbit/s) 
Device Address 1 
Number Of Open Pipes 1 

Device Descriptor Microsoft IntelliMouse® Optical
Offset Field Size Value Description 
0 bLength 1 12h  
1 bDescriptorType 1 01h Device 
2 bcdUSB 2 0110h USB Spec 1.1 
4 bDeviceClass 1 00h Class info in Ifc Descriptors 
5 bDeviceSubClass 1 00h  
6 bDeviceProtocol 1 00h  
7 bMaxPacketSize0 1 08h 8 bytes 
8 idVendor 2 045Eh  
10 idProduct 2 0039h  
12 bcdDevice 2 0121h 1.21 
14 iManufacturer 1 01h "Microsoft" 
15 iProduct 1 02h "Microsoft IntelliMouse. Optical" 
16 iSerialNumber 1 00h  
17 bNumConfigurations 1 01h  

Configuration Descriptor 1 Bus Powered, 100 mA
Offset Field Size Value Description 
0 bLength 1 09h  
1 bDescriptorType 1 02h Configuration 
2 wTotalLength 2 0022h  
4 bNumInterfaces 1 01h  
5 bConfigurationValue 1 01h  
6 iConfiguration 1 00h  
7 bmAttributes 1 A0h Bus Powered, Remote Wakeup 
 4..0: Reserved  ...00000   
 5: Remote Wakeup  ..1.....  Yes 
 6: Self Powered  .0......  No, Bus Powered 
 7: Reserved (set to one)
(bus-powered for 1.0)  1.......   
8 bMaxPower 1 32h 100 mA 

Interface Descriptor 0/0 HID, 1 Endpoint
Offset Field Size Value Description 
0 bLength 1 09h  
1 bDescriptorType 1 04h Interface 
2 bInterfaceNumber 1 00h  
3 bAlternateSetting 1 00h  
4 bNumEndpoints 1 01h  
5 bInterfaceClass 1 03h HID 
6 bInterfaceSubClass 1 01h Boot Interface 
7 bInterfaceProtocol 1 02h Mouse 
8 iInterface 1 00h  

HID Descriptor 
Offset Field Size Value Description 
0 bLength 1 09h  
1 bDescriptorType 1 21h HID 
2 bcdHID 2 0100h 1.00 
4 bCountryCode 1 00h  
5 bNumDescriptors 1 01h  
6 bDescriptorType 1 22h Report 
7 wDescriptorLength 2 0048h 72 bytes 

Endpoint Descriptor 81 1 In, Interrupt, 10 ms
Offset Field Size Value Description 
0 bLength 1 07h  
1 bDescriptorType 1 05h Endpoint 
2 bEndpointAddress 1 81h 1 In 
3 bmAttributes 1 03h Interrupt 
 1..0: Transfer Type  ......11  Interrupt 
 7..2: Reserved  000000..   
4 wMaxPacketSize 2 0004h 4 bytes 
6 bInterval 1 0Ah 10 ms 

Interface 0 HID Report Descriptor Mouse
Item Tag (Value) Raw Data 
Usage Page (Generic Desktop) 05 01  
Usage (Mouse) 09 02  
Collection (Application) A1 01  
    Usage (Pointer) 09 01  
    Collection (Physical) A1 00  
        Usage Page (Button) 05 09  
        Usage Minimum (Button 1) 19 01  
        Usage Maximum (Button 5) 29 05  
        Logical Minimum (0) 15 00  
        Logical Maximum (1) 25 01  
        Report Size (1) 75 01  
        Report Count (5) 95 05  
        Input (Data,Var,Abs,NWrp,Lin,Pref,NNul,Bit) 81 02  
        Report Size (3) 75 03  
        Report Count (1) 95 01  
        Input (Cnst,Ary,Abs) 81 01  
        Usage Page (Generic Desktop) 05 01  
        Usage (X) 09 30  
        Usage (Y) 09 31  
        Usage (Wheel) 09 38  
        Logical Minimum (-127) 15 81  
        Logical Maximum (127) 25 7F  
        Report Size (8) 75 08  
        Report Count (3) 95 03  
        Input (Data,Var,Rel,NWrp,Lin,Pref,NNul,Bit) 81 06  
    End Collection C0  
    Usage Page 05 FF  
    Usage 09 02  
    Logical Minimum (0) 15 00  
    Logical Maximum (1) 25 01  
    Report Size (1) 75 01  
    Report Count (1) 95 01  
    Feature (Data,Var,Abs,NWrp,Lin,NPrf,NNul,NVol,Bit) B1 22  
    Report Size (7) 75 07  
    Report Count (1) 95 01  
    Feature (Cnst,Ary,Abs,NWrp,Lin,Pref,NNul,NVol,Bit) B1 01  
End Collection C0

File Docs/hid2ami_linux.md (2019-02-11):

# FLASHING HID2AMI UNDER LINUX

You will need dfu-util from http://dfu-util.sourceforge.net. A recent version (>= 0.8) is recommended, so you will probably need to download and compile it. Versions included in mainstream distributions might not work. This procedure has been tested with the current git version, as of 5 Feb 2019.

## FLASHING THE BOOTLOADER
- Set HID2AMI in DFU-BOOT mode, by selecting position 2-3 for both "BOOT0" and "PA9BOOT" jumpers
- MAKE SURE THAT HID2AMI IS NOT CONNECTED TO YOUR AMIGA MOUSE/JOY PORT
- Connect HID2AMI to any USB port of your PC, by mean of the A-A USB Cable
- Wait 5-10 seconds, then you should see something like the following in your `dmesg`:
```
usb 1-1: new full-speed USB device number 57 using xhci_hcd
usb 1-1: New USB device found, idVendor=0483, idProduct=df11
usb 1-1: New USB device strings: Mfr=1, Product=2, SerialNumber=3
usb 1-1: Product: STM32 0x418 DFU Bootloade
usb 1-1: Manufacturer: STMicroelectronics
usb 1-1: SerialNumber: STM32
```
On my system it takes several seconds and quite a bit of weird errors are reported, but eventually it will settle down to that.
- Run `sudo dfu-util --list`, you should get some output similar to the following:
```
dfu-util 0.9

Copyright 2005-2009 Weston Schmidt, Harald Welte and OpenMoko Inc.
Copyright 2010-2019 Tormod Volden and Stefan Schmidt
This program is Free Software and has ABSOLUTELY NO WARRANTY
Please report bugs to http://sourceforge.net/p/dfu-util/tickets/

Deducing device DFU version from functional descriptor length
Found DFU: [0483:df11] ver=2200, devnum=57, cfg=1, intf=0, path="1-1", alt=1, name="@Option Bytes  /0x1FFFF800/01*016 e", serial="STM32"
Found DFU: [0483:df11] ver=2200, devnum=57, cfg=1, intf=0, path="1-1", alt=0, name="@Internal Flash  /0x08000000/128*002Kg", serial="STM32"
Found Runtime: [05ac:8289] ver=0137, devnum=6, cfg=1, intf=3, path="1-3.3", alt=0, name="UNKNOWN", serial="UNKNOWN"
```
- Focus on the last few lines: these list all devices that support DFU mode connected to the system. Some of them will belong to HID2AMI, but others might refer to other peripherals connected to your computer  (or built into it!). You might want to run the command again with HID2AMI disconnected to see if it finds something in your computer. Two of the lines will refer to HID2AMI, you can identify them as they will be saying `serial="STM32"`. One of those will also say `name="@Internal Flash..."` and this will be the device we need to flash. In order to do so, we need a way to uniquely identify it: in the above case, using the `intf=0` and `alt=0` attributes is enough. Your mileage may vary, be careful as you might damage other devices if you flash them with the wrong firmware. You can also brick your HID2AMI if you change its `Option Bytes`, so please be very careful not to touch them! Let me repeat: **you must take care so that you only work on the `Internal Flash` of your `STM32` device**!
- Download the bootloader from https://github.com/EmberHeavyIndustries/HID2AMI/blob/master/Firmware/HID2AMIBOOTLOADER.dfu, change to the directory you saved it to and run: `sudo dfu-util -D HID2AMIBOOTLOADER.dfu -i 0 -a 0`, where `-i` and `-a` are followed by the `intf` and `alt` IDs found above. If you need to pass extra parameters to select the correct device, run `dfu-util --help` to see the full option list and tune the command appropriately. You should get the following output:
```
dfu-util 0.9

Copyright 2005-2009 Weston Schmidt, Harald Welte and OpenMoko Inc.
Copyright 2010-2019 Tormod Volden and Stefan Schmidt
This program is Free Software and has ABSOLUTELY NO WARRANTY
Please report bugs to http://sourceforge.net/p/dfu-util/tickets/

Match vendor ID from file: 0483
Match product ID from file: 0000
Deducing device DFU version from functional descriptor length
Opening DFU capable USB device...
ID 0483:df11
Run-time device DFU version 011a
Claiming USB DFU Interface...
Setting Alternate Setting #0 ...
Determining device status: state = dfuIDLE, status = 0
dfuIDLE, continuing
DFU mode device DFU version 011a
Device returned transfer size 2048
DfuSe interface name: "Internal Flash  "
file contains 1 DFU images
parsing DFU image 1
Target name: HID2AMIBOOT_1.3.0
image for alternate setting 0, (1 elements, total size = 21712)
parsing element 1, address = 0x08000000, size = 21704
Download	[=========================] 100%        21704 bytes
Download done.
done parsing DfuSe file
```
- **NOTE:** If you are not flashing the device for the first time, or if for any reason you get the error message `ERASE_PAGE not correctly executed`, try adding `-s 0:force:unprotect` to the above command line and wait a minute (literally, i.e.: 60 seconds), then retry the original command.

## RETRIEVING YOUR PERSONAL BOARD CODE
If everything went fine, your board can now boot from the BOOTLOADER and is ready to be flashed with the HID2AMI App.

- Set HID2AMI in BOOTLOADER mode, by selecting position 1-2 for "BOOT0" and position 2-3 for "PA9BOOT".
- MAKE SURE THAT HID2AMI IS NOT CONNECTED TO YOUR AMIGA MOUSE/JOY PORT.
- Connect HID2AMI to any USB port of your PC, by mean of the A-A USB Cable: the bootloader should take control, and you should see the activity led on board (LED1) blinking rapidly.
- Run again `sudo dfu-util --list`. The output should not be much different from before, but this time the `ver` field will be different:
```
- Found DFU: [0483:df11] ver=59eb, devnum=88, cfg=1, intf=0, path="1-1", alt=0, name="@Internal Flash   /0x08000000/06*002Ka,122*002Kg", serial="00000000010C"
```
- In order to get a properly signed app, working tied to your board, you have to ask the author for it, by sending him an [email](mailto:EmberHEavyIndustries@gmail.com) together with your personal code, which is what is reported in the `ver` field  (in my case it is `59eb`, yours should obviously be different).

## FLASHING THE HID2AMI APP
The author will send you your personalized app file, in the form "HID2AMIAPP.XXXX.dfu".
- Boot again HID2AMI in BOOTLOADER mode (just as above)
- Run again `sudo dfu-util --list` and check again the IDs of your device. If they have changed, tune the following commands appropriately.
- Run `sudo dfu-util -D HID2AMIAPP-1.7.2-59EB.dfu -i 0`. Note that the `-a` option is no longer necessary, since the `Option Bytes` entry should not appear anymore. Your output should look like the following:
```
dfu-util 0.9

Copyright 2005-2009 Weston Schmidt, Harald Welte and OpenMoko Inc.
Copyright 2010-2019 Tormod Volden and Stefan Schmidt
This program is Free Software and has ABSOLUTELY NO WARRANTY
Please report bugs to http://sourceforge.net/p/dfu-util/tickets/

Match vendor ID from file: 0483
Match product ID from file: 0000
Deducing device DFU version from functional descriptor length
Opening DFU capable USB device...
ID 0483:df11
Run-time device DFU version 011a
Claiming USB DFU Interface...
Setting Alternate Setting #0 ...
Determining device status: state = dfuIDLE, status = 0
dfuIDLE, continuing
DFU mode device DFU version 011a
Device returned transfer size 1024
DfuSe interface name: "Internal Flash   "
file contains 1 DFU images
parsing DFU image 1
Target name: HID2AMI_1.7.2_59EB
image for alternate setting 0, (1 elements, total size = 81928)
parsing element 1, address = 0x0800c000, size = 81920
Download	[=========================] 100%        81920 bytes
Download done.
done parsing DfuSe file
```
- If no errors are reported, you're done! DISCONNECT you HID2AMI board from your PC, put the HID2AMI board in APP mode by by selecting position 1-2 for both "BOOT0" and "PA9BOOT" jumpers, and connect it to any Mouse/Joy port of your Amiga.
- Enjoy!

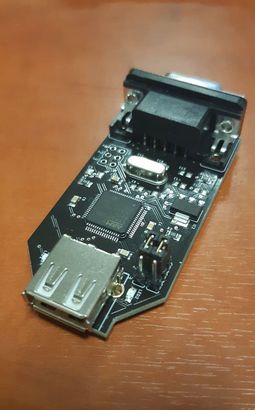
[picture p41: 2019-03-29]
Pics/Hid2AMI_Rev1.1.3D_10.jpg

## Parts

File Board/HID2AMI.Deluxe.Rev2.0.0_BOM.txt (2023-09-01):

Partlist exported from E:/Amiga/Schematics/HID2AMI/HID2AMI.Deluxe.Rev2.0.0.sch at 11/11/2022 2:38 PM

Qty Value               Device              Package   Parts                                     Description                                                           MF        MPN    OC_FARNELL OC_NEWARK POPULARITY SPICEPREFIX
1                       F09HP               F09HP     X3                                        SUB-D                                                                                  unknown    unknown                         
2                       JP2E                JP2       B0, PA9                                   JUMPER                                                                                                      34                    
2                       LEDSML0805          SML0805   ACT, PWR                                  LED                                                                                                                               
8   100k                R-EU_M0805          M0805     R1, R4, R5, R6, R7, R8, R9, R10           RESISTOR, European symbol                                                                                              R          
9   100n                C-EUC0805           C0805     C1, C2, C3, C4, C5, C6, C10, VCAP1, VCAP2 CAPACITOR, European symbol                                                                                             C          
2   10k                 R-EU_M0805          M0805     R2, R3                                    RESISTOR, European symbol                                                                                              R          
1   10u                 C-EUC0805           C0805     C9                                        CAPACITOR, European symbol                                                                                             C          
2   22p                 C-EUC0805           C0805     C7, C8                                    CAPACITOR, European symbol                                                                                             C          
1   BSS138              BSS138              SOT23     Q2                                        BSS138 N-Channel Logic Level Enhancement Mode Field Effect Transistor Fairchild BSS138 9845330    67R2009                         
1   CRYSTALS-NOGND-HC49 CRYSTALS-NOGND-HC49 HC49      X1                                        CRYSTALS CAN NOT GROUNDED                                                                                   0                     
1   LM1117MPX-3.3       LM1117MPX-3.3       SOT223    IC1                                                                                                                                                                         
1   PN87520-S           PN87520-S           PN87520-S X2                                                                                                                               unknown    unknown                         
1   STM32F105RXT6       STM32F105RXT6       TQFP64    U1                                        STM32F105/ 64pin LQFP  105

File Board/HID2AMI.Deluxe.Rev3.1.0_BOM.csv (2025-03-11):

Designator | Footprint | Quantity | Value | LCSC Part #
ACT1 | 805 | 1 | ACT | C2296
C1, C10, C2, C3, C4, C5, C6 | 603 | 7 | 100n
C7, C8 | 603 | 2 | 20p
C9 | 603 | 1 | 10u
FWUPD1 | SW-SMD_MSS12C02LS-HB2.0-1 | 1 | MSS12C02LS-BB2.0 | C3008585
J1 | DSUB-9_Female_EdgeMount_P2.77mm | 1 | DE9_Receptacle | C138804
LDS1 | 805 | 1 | STAT1 | C2296
LDS2 | 805 | 1 | STAT2 | C2296
MAP1 | SW-SMD_4P-L2.6-W1.6-P0.75-LS3.0 | 1 | ~ | C913784
MODE1 | SW_DIP_SPSTx03_Slide_KingTek_DSHP03TJ_W5.25mm_P1.27mm_JPin | 1 | SW_DIP_x03 | C3293143
Q1 | SOT-23 | 1 | BSS138 | C5279927
R1, R3, R4, R5 | 603 | 4 | 10k
R2 | 603 | 1 | 100k
RN1, RN2, RN3 | R_Array_Convex_4x0603 | 3 | 100k | C173315
U1 | SOT-89-3 | 1 | AMS1117-3.3 | C5120796
U2 | LQFP-64_10x10mm_P0.5mm | 1 | STM32F105RBTx | C8349
USB1 | USB-A-SMD_10.0-QTJ6.3 | 1 | 10.0 QTJ6.3 | C404966
Y1 | Crystal_SMD_3225-4Pin_3.2x2.5mm_HandSoldering | 1 | 8Mhz | C2682774

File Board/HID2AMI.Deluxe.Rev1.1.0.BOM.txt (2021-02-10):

|Part | Value  | Device |  Package | Man./Opt.|
|---|--- |---|---|---|
|BOOT0  | JP2E | JP1 | JUMPER | |
|PA9BOOT| JP2E | JP2 | JUMPER | |
| | | | | |
|C1 | 100n | C-EUC0805 |  C0805 | Optional |
|C2 | 100n | C-EUC0805 |  C0805 | Optional |
|C3 | 10u | C-EUC1206 |  C1206 | Optional |
|C4 | 100n | C-EUC0805 |  C0805 | MANDATORY|
|C5 | 100n | C-EUC0805 |  C0805 | MANDATORY|
|C6 | 100n | C-EUC0805 |  C0805 | Optional |
|C7 | 100n | C-EUC0805 |  C0805 | Optional |
|C8 | 100n | C-EUC0805 |  C0805 | Optional |
|C9 | 100n | C-EUC0805 |  C0805 | MANDATORY|
|C10 |  22p | C-EUC0805 |  C0805 | MANDATORY|
|C11 |  22p | C-EUC0805 |  C0805 | MANDATORY|
|C12 | 100n | C-EUC0805 |  C0805 | MANDATORY|
|C13 | 10u | C-EUC1206 |  C1206 | Optional |
|C14 | 100n | C-EUC0805 |  C0805 | MANDATORY|
|C15 | 100n | C-EUC0805 |  C0805 | Optional |
|C16 | 100n | C-EUC0805 |  C0805 | Optional |
| | | | | |
|IC1 |LM1117-3.3| LM1117MPX-3.3  |  SOT223 | MANDATORY|
| | | | | |
|LED1 | | LEDSML0805 |  SML0805 | Optional |
|LED2 | | LEDSML0805 |  SML0805 | Optional |
| | | | | |
|Q1 | 8MHz | CRYSTALHC49S |  HC49/S | MANDATORY|
| | | | | |
|Q2 | BSS138 | BSS138 |  SOT23 | MANDATORY|
|Q3 | BSS138 | BSS138 |  SOT23 | MANDATORY|
|Q4 | BSS138 | BSS138 |  SOT23 | MANDATORY|
|Q5 | BSS138 | BSS138 |  SOT23 | MANDATORY|
|Q6 | BSS138 | BSS138 |  SOT23 | MANDATORY|
|Q7 | BSS138 | BSS138 |  SOT23 | MANDATORY|
|Q8 | BSS138 | BSS138 |  SOT23 | MANDATORY|
| | | | | |
|R1 | --- | -- |  -- | NA |
|R2 | 100k | R-EU_M0805 |  M805 | MANDATORY|
|R3 | 10k-33k  | R-EU_M0805 |  M805 | Optional |
|R4 | 10k-33k  | R-EU_M0805 |  M805 | Optional |
|R5 | 100k | R-EU_M0805 |  M805 | MANDATORY|
|R6 | 100k | R-EU_M0805 |  M805 | MANDATORY|
|R7 | 100k | R-EU_M0805 |  M805 | MANDATORY|
|R8 | 100k | R-EU_M0805 |  M805 | MANDATORY|
|R9 | 100k | R-EU_M0805 |  M805 | MANDATORY|
|R10 | 100k | R-EU_M0805 |  M805 | MANDATORY|
|R11 | 100k | R-EU_M0805 |  M805 | MANDATORY|
| | | | | |
|U1 | F105RBT6 | STM32F105RBT6  |  LQFP64 | MANDATORY|
| | | | | |
|X1 | | USB-CONNECTOR  | | MANDATORY|
|X2 | | F09HP D-SUB9 |  F09HP | MANDATORY|
| | | | | |

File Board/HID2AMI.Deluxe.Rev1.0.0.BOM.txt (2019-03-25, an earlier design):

|Part | Value  | Device |  Package | Rev 1.0  |
|---|--- |---|---|---|
|BOOT0  | JP2E | JP1 | JUMPER | |
|PA9BOOT| JP2E | JP2 | JUMPER | |
| | | | | |
|C1 | 100n | C-EUC0805 |  C0805 | Optional |
|C2 | 10u | C-EUC1206 |  C1206 | Optional |
|C3 | 100n | C-EUC0805 |  C0805 | Optional |
|C4 | 100n | C-EUC0805 |  C0805 | Optional |
|C5 | 100n | C-EUC0805 |  C0805 | MANDATORY|
|C6 | 100n | C-EUC0805 |  C0805 | MANDATORY|
|C7 | 22p | C-EUC0805 |  C0805 | MANDATORY|
|C8 | 22p | C-EUC0805 |  C0805 | MANDATORY|
|C9 | 100n | C-EUC0805 |  C0805 | Optional |
|C10 | 10u | C-EUC1206 |  C1206 | Optional |
|C11 | 100n | C-EUC0805 |  C0805 | MANDATORY|
|C12 | 100n | C-EUC0805 |  C0805 | MANDATORY|
|C13 | 100n | C-EUC0805 |  C0805 | Optional |
|C14 | 100n | C-EUC0805 |  C0805 | Optional |
|C15 | 100n | C-EUC0805 |  C0805 | Optional |
|C16 | 100n | C-EUC0805 |  C0805 | Optional |
| | | | | |
|IC1 |LM1117-3.3| LM1117MPX-3.3  |  SOT223 | MANDATORY|
| | | | | |
|LED1 | | LEDSML0805 |  SML0805 | Optional |
|LED2 | | LEDSML0805 |  SML0805 | Optional |
| | | | | |
|Q1 | 8MHz | CRYSTALHC49S |  HC49/S | MANDATORY|
| | | | | |
|Q2 | BSS138 | BSS138 |  SOT23 | MANDATORY|
|Q3 | BSS138 | BSS138 |  SOT23 | MANDATORY|
|Q4 | BSS138 | BSS138 |  SOT23 | MANDATORY|
|Q5 | BSS138 | BSS138 |  SOT23 | MANDATORY|
|Q6 | BSS138 | BSS138 |  SOT23 | MANDATORY|
|Q7 | BSS138 | BSS138 |  SOT23 | MANDATORY|
|Q8 | BSS138 | BSS138 |  SOT23 | MANDATORY|
| | | | | |
|R1 | 0k | SHORT |  M805 | MANDATORY|
|R2 | 100k | R-EU_M0805 |  M805 | MANDATORY|
|R3 | 0k | SHORT |  M805 | MANDATORY|
|R4 | 1k-10k | R-EU_M0805 |  M805 | Optional |
|R5 | 1k-10k | R-EU_M0805 |  M805 | Optional |
|R6-R12 | --- | -- |  -- | NA |
|R13 | 100k | R-EU_M0805 |  M805 | MANDATORY|
|R14 | 100k | R-EU_M0805 |  M805 | MANDATORY|
|R15 | 100k | R-EU_M0805 |  M805 | MANDATORY|
|R16 | 100k | R-EU_M0805 |  M805 | MANDATORY|
|R17 | 100k | R-EU_M0805 |  M805 | MANDATORY|
|R18 | 100k | R-EU_M0805 |  M805 | MANDATORY|
|R19 | 100k | R-EU_M0805 |  M805 | MANDATORY|
|R20 | 0k | SHORT |  M805 | MANDATORY|
| | | | | |
|U1 | F105RBT6 | STM32F105RBT6  |  LQFP64 | MANDATORY|
| | | | | |
|X1 | | USB-CONNECTOR  | | MANDATORY|
|X3 | | F09HP D-SUB9 |  F09HP | MANDATORY|
| | | | | |

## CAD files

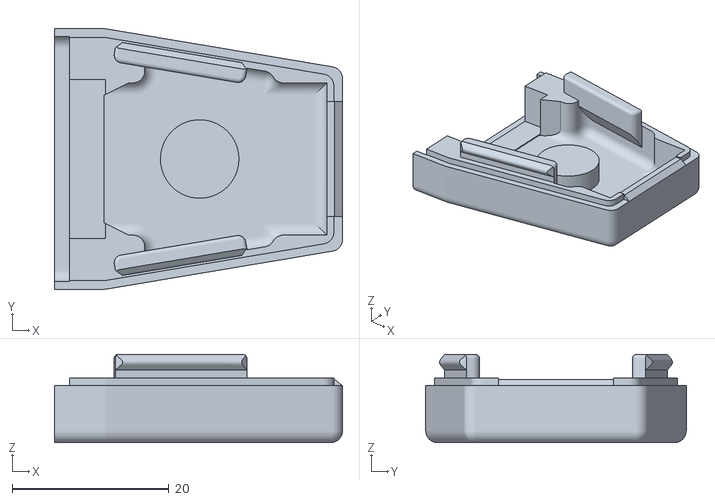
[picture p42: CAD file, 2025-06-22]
Docs/HID2AmiV3_Base.stl
36.7 x 33.2 x 11.2

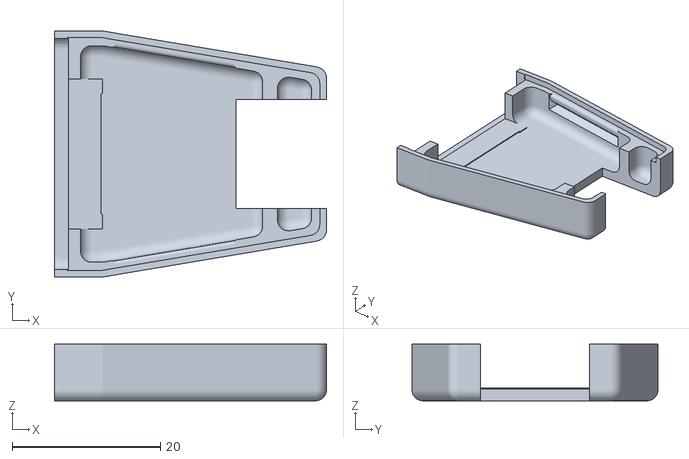
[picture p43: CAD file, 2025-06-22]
Docs/HID2AmiV3_Lid.stl
36.7 x 33.2 x 7.65

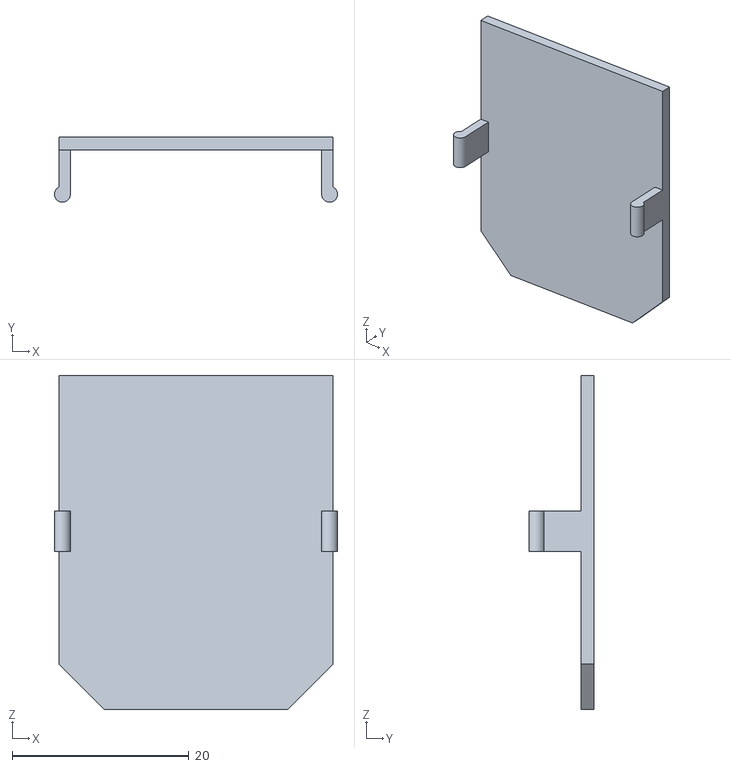
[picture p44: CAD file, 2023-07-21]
Docs/HID2AMI_CERV_cover.stl
32.0 x 7.40 x 37.8

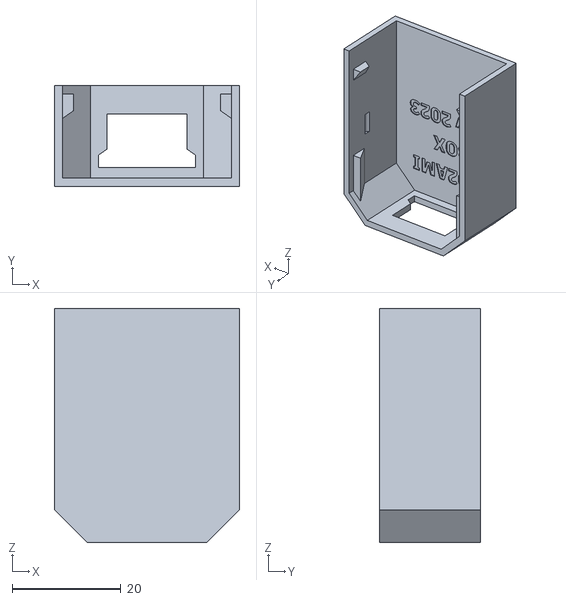
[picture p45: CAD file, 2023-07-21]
Docs/HID2AMI_CERV_box.stl
34.0 x 18.5 x 43.0

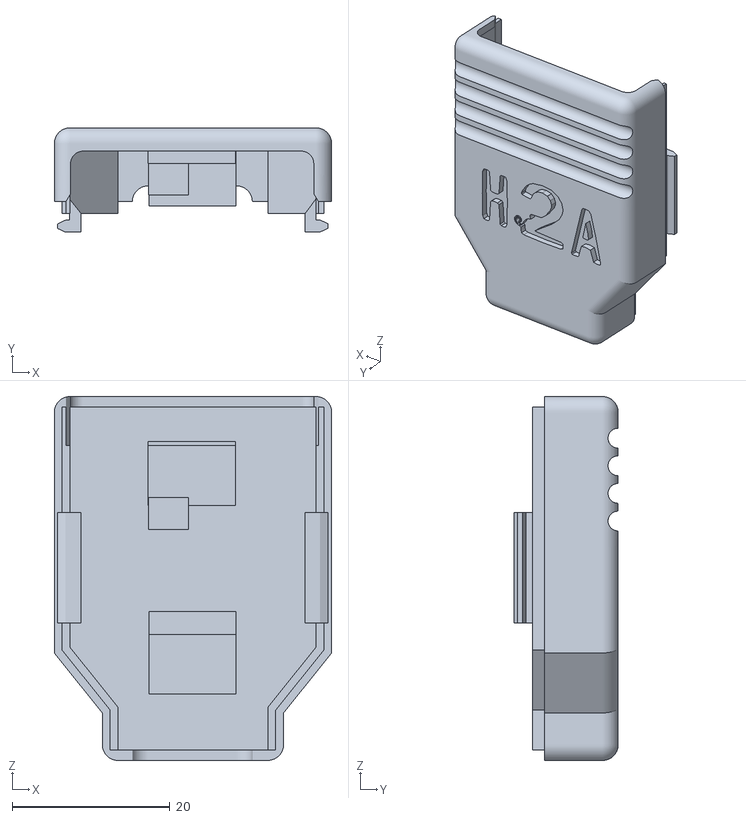
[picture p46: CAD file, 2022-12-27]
Docs/HID2AMI_ShellUpper.stl
35.1 x 13.2 x 46.1

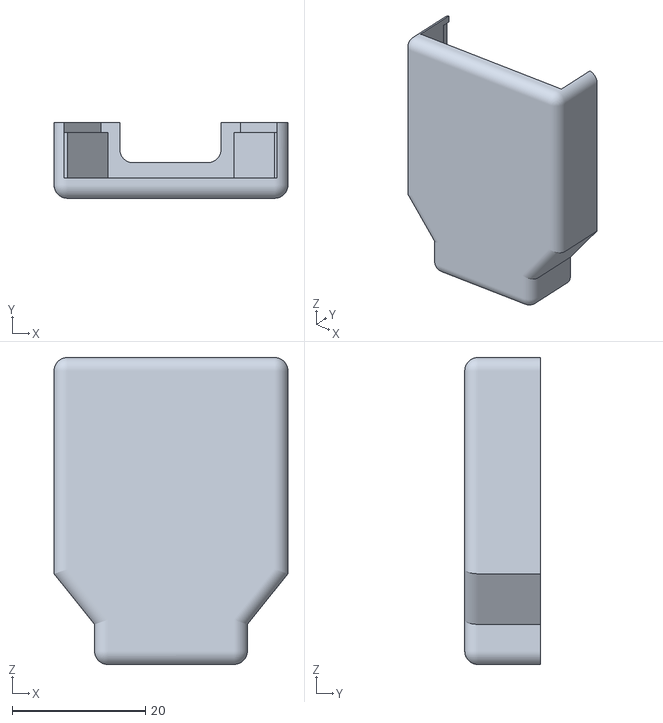
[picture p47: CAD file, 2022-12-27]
Docs/HID2AMI_ShellLower.stl
35.1 x 11.4 x 46.1

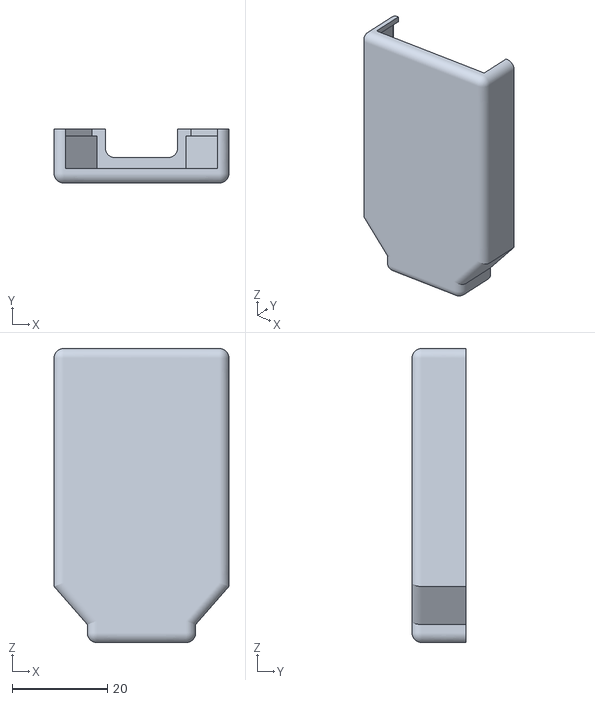
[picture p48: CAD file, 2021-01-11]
Docs/88.EmberHID2AMI.LowerShell_1.stl
36.8 x 11.4 x 61.8

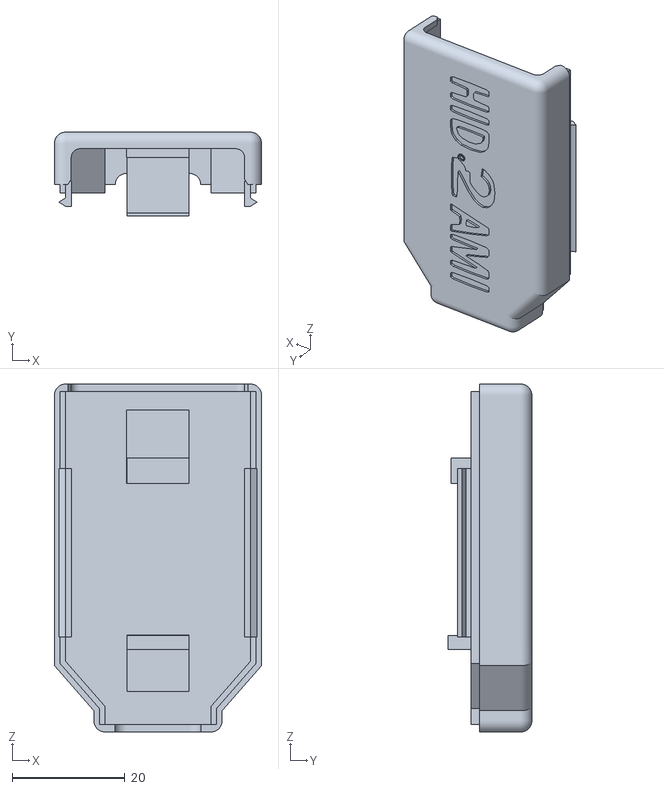
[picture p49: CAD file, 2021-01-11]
Docs/88.EmberHID2AMI.UpperShell_1.stl
36.8 x 14.9 x 61.8

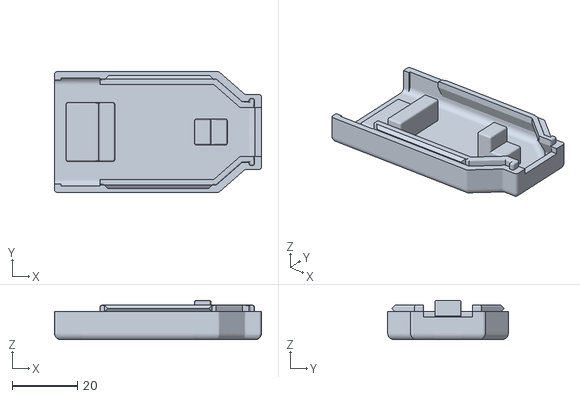
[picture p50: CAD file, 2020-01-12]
Docs/HID2AMI_Top.stl
63.5 x 37.0 x 12.1

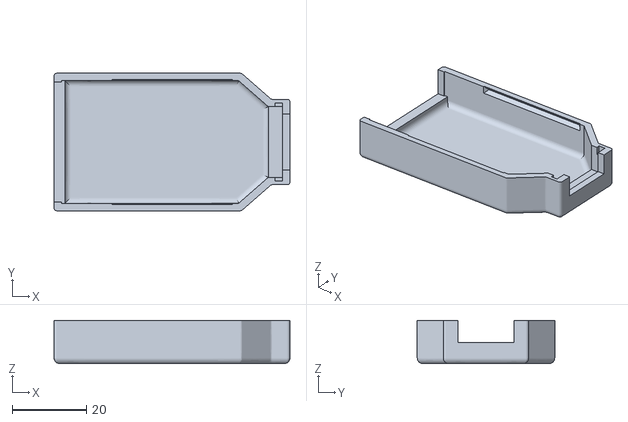
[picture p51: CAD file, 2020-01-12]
Docs/HID2AMI_Bottom.stl
63.5 x 37.0 x 11.6

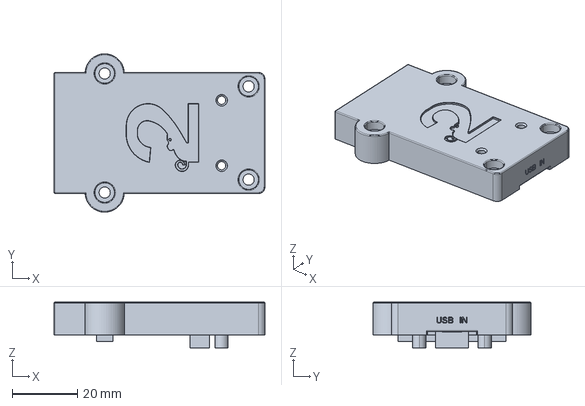
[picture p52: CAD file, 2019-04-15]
Docs/top_cover_Final.stp
64.5 x 48.4 x 14.0 mm

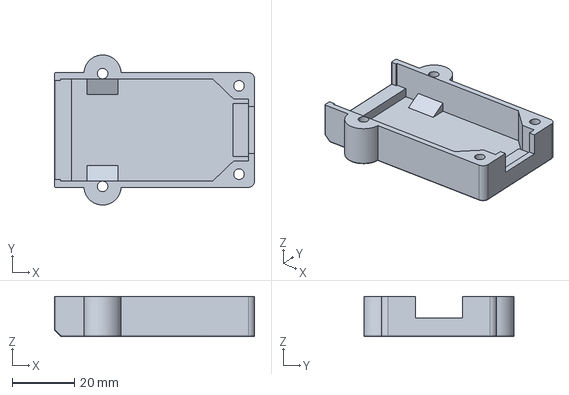
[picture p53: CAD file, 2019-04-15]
Docs/bottom_cover_Final.stp
64.5 x 48.4 x 13.0 mm

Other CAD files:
Docs/bottom_cover_final.stl
Docs/top_cover_final.stl

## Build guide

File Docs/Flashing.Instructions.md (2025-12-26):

### **FLASHING INSTRUCTIONS**

#### **PREREQUISITES**
In order to be able to flash both the bootloader and the HID2AMI app, you need:
- A MS-Windows or Linux PC
- An A-A USB cable (https://www.google.com/search?q=a-a+usb+cable)
- for Windows: the free ST DFU Tools. Download the package from here (https://www.st.com/en/development-tools/stsw-stm32080.html)
- for Linux: the free dfu-util from http://dfu-util.sourceforge.net.

### **FLASHING IN LINUX**
Thanks to the precious & talented friend Sukkopera (https://github.com/SukkoPera), HID2AMI App can be flashed within a Linux environment as well as its Windows counterpart. You can find the detailed procedure here: [Sukkopera's Linux Flashing instructions](https://github.com/EmberHeavyIndustries/HID2AMI/blob/master/Docs/hid2ami_linux.md)
Thank you SukkoPera !

### **FLASHING IN WINDOWS**

#### **FLASHING THE BOOTLOADER**
- Install the ST DFU Tool package on your Windows machine. Make sure you have the ST DFU-USB driver installed (in case something went wrong, you can manually install them from the DFU Tool's directory)
- Set HID2AMI in DFU-BOOT mode, by selecting position 2-3 for both "BOOT0" and "PA9BOOT" jumpers (*)
- MAKE SURE THAT HID2AMI IS NOT CONNECTED TO YOUR AMIGA MOUSE/JOY PORT
- Connect HID2AMI to any USB port of your PC, by mean of the A-A USB Cable
- After few seconds, HID2AMI should be recognized by Windows as "ST Device in DFU Mode"
- Launch "DfuSeDemo" App from ST Tools package. You should see a form like this one, showing your HID2AMI has booted in DFU mode and has been recognized properly 

**(*) in newest v2.x+ / v3.x+ adapters the "BOOT0" jumper is replaced by an open bridge-pad. To emulate closing the 2-3 position for BOOT0, just short these pads with any conductive tip at the moment of powering up the device for flashing.**

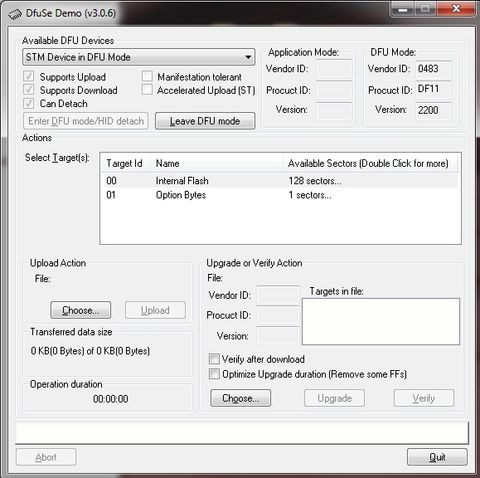
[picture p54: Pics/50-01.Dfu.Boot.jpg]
DFU-BOOT

- Select the HID2AMIBOOTLOADER.dfu file you previosly downloaded from [here](https://github.com/EmberHeavyIndustries/HID2AMI/blob/master/Firmware/HID2AMIBOOTLOADER.dfu) by pressing "Choose" under "Upgrade or Verify Action". 
You should come to a condition like this          

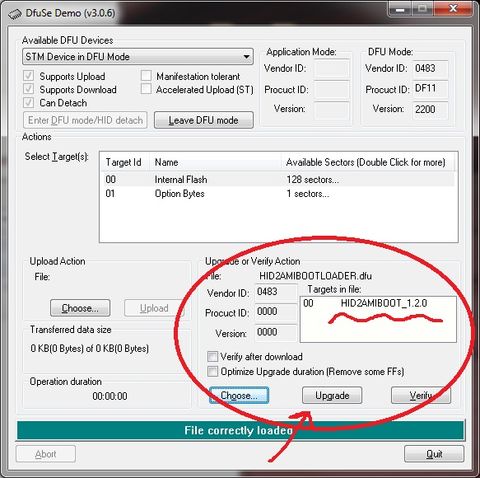
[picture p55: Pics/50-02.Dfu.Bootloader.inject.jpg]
DFU-BOOT-INJECT

- Press "Upgrade" button and wait the process to finish with success.

#### **RETRIEVING YOUR PERSONAL BOARD CODE**
If everything went fine, your board now can boot from the BOOTLOADER and is ready to be loaded with the HID2AMI App
- Set HID2AMI in BOOTLOADER mode, by selectin position 1-2 for "BOOT0" and position 2-3 for "PA9BOOT". **Note: newer Rev1.1 preassembled boards do not have BOOT0 jumper installed, since it is not needed to update the App. If it is your case, simply ignore BOOT0**

**Note: on newer Rev3.x+ boards simply move the switch from "RN" (run) to "F" (firmware) position**

- MAKE SURE THAT HID2AMI IS NOT CONNECTED TO YOUR AMIGA MOUSE/JOY PORT
- Connect HID2AMI to any USB port of your PC, by mean of the A-A USB Cable: the bootloader should take control, and you should see the activity led on board (lower led near usb connector) fastly blinking
- Look at DfuSeDemo window: you should see something like as follows. Note down the four characters you see near "Version" field

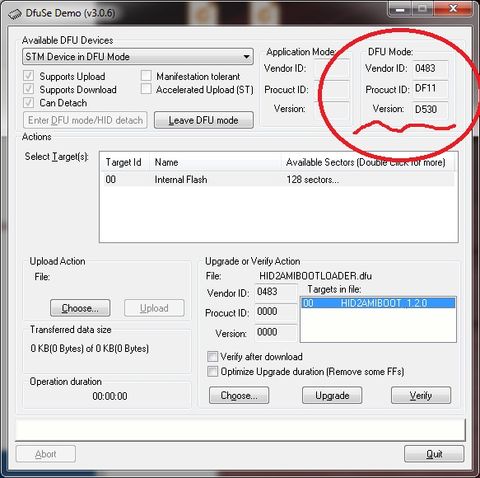
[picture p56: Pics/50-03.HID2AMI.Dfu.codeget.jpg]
DFU-BOOTLOADED

- In order to get a properly signed app, working tied to your board, you have to ask it from the author, by sending him an [email](mailto:EmberHEavyIndustries@gmail.com) together with your personal code, which is the four character as above (in the case of the picture is "D530", yours should obviously be different)

#### **FLASHING THE HID2AMI APP**
- Once received your personalized app file, in the form "HID2AMIAPP.XXXX.dfu", boot again HID2AMI in BOOTLOADER mode (same as above), "Choose" the app file "HID2AMIAPP.XXXX.dfu" and press "Upgrade" 
- To boot in BOOTLOADER mode just set "PA9BOOT" jumper in position 2-3 (for Rev3.x+ keep the switch on "F" position)

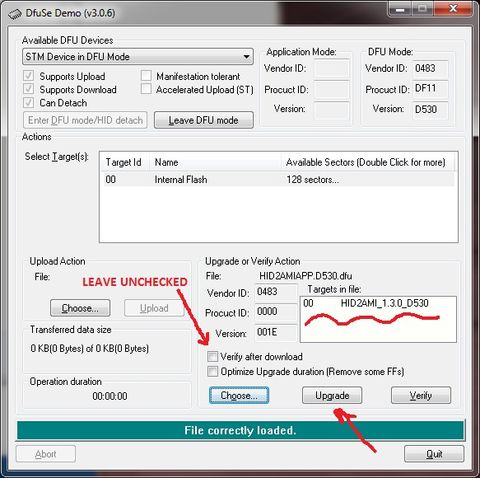
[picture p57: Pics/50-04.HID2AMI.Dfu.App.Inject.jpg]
DFU-LOADAPP

- You're done ! Put the HID2AMI board in APP mode by by selecting position 1-2 for both "BOOT0" and "PA9BOOT" jumpers (for Rev3.x+ put the switch back on  "RN" position) , **DISCONNECT you HID2AMI board from your Windows PC** and connect it to any Mouse/Joy port of your Amiga
- Enjoy !

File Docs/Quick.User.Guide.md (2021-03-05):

# **HID2AMI QUICK USER GUIDE** 

## **IMPORTANT NOTE READ FIRST**

While playing with HID2AMI and your Amiga, always remember two important things:

- HID2AMI does not have any external power source, so its supply power comes from your Amiga. As a direct consequence, your Amiga will have to supply power to any USB peripheral device cascadely connected to HID2AMI. All of this happens through the Mouse/Joy ports, which therefore must bear the whole supplying current for the ensemble. Whilst there isn't generally any problems at all with typical consumer peripherals, you must avoid connecting high-power-demanding peripherals, without knowledge of what you are doing: in extreme cases you could blow out your Amiga's mouse/joy port current limiting resistors.

- Never connect HID2AMI's USB port to your PC (or any other active device) while it (HID2AMI) is connected to your Amiga's mouse/joy port, no matter if your Amiga is turned off. Simple rule to follow: upgrade flashing HID2AMI must be performed with the board's DB9 (joy) connector unplugged from everyhting.  

## **GETTING STARTED**

Getting started is quite strightforward: 

- connect HID2AMI to your Amiga's mouse or joypad port (this could be done at any moment, no matters if Amiga is powered on)
- you should notice the "power led" (usually red) firmly lit, and the "running led" (usually green or yellow) blinking roughly twice a second

### **MOUSE OPERATIONS**

- Connect a compatible mouse to the USB port of HID2AMI: the "running led" should slow down to roughly blinking once a second: the mouse has been recognized and initialized
- That's all ! Start playing with your Mouse, and consider customizing its workign parameters as follows

#### **MOUSE CUSTOM SETTINGS**

Default pointer speed, recognized by your Amiga, depends upon the connected mouse's working parameters, in terms of frequency of position updates and axis bit resolution.
HID2AMI allows you to dynamically adjust the pointer speed, slowing/speeding-up within three different degrees.

- To dynamically adjust pointer speed (it can be done at any moment): 
  - Press all three mouse button together: running led stops blinking and the board enters pointer setting mode
  - Roll your mousewheel forward to slowdown the pointer travel speed by one step (0% - 25% - 50%)
  - Roll your mousewheel backwards to speedup the pointer travel speed by one step (0% - 25% - 50%)
  - Press again all three mouse buttons together: your current settings will be saved and th eboard will return in default running mode

HID2AMI will store and retrieve your settings next time you will connect the mouse. If you have different mice brand/models, HID2AMI automatically saves a dedicated profile for each one, and automatically retrieves it when that particular mouse is connected.

### **GAMEPAD OPERATIONS**

- Connect a compatible joy/gamepad to the USB port of HID2AMI: the "running led" should slow down to roughly blinking once a second: the pad has been recognized and initialized
- You can set your pad to work either in Analog or Digital mode, according to your preferences; start then playing with your pad, and consider customizing its workign parameters as follows
- By default, HID2AMI maps the first six gamepad buttons to the sequence: Amiga1 - Amiga2 - UP - DOWN - Amiga1 - Amiga2. Unfortunately any single different pad declares its buttons in somewhat a random order, so it is not possible for HID2AMI to be sure that the automatic mapping meets your tastes. So, consider customizing your settings as follows

#### **GAMEPAD CUSTOM SETTINGS**

HID2AMI allows the user to freely customize the mapping of any pad's first 4 buttons, more than enough to play any possible Amiga game. Furthermore, HID2AMI automatically saves the gamepad custom mapping into its internal flash, and retrieves it when the pad is connected again. Different brand/models of pads are automatically recognized, and the respective custom profile saves are stored and recalled without any need of user's intervention.

- **To start and perform the mapping procedure**
  - press all together the first 4 buttons of the pad AND pull the left trigger DOWN
  - the running led stops blinking and stands firmly lit: you are in mapping mode
  - press in sequence the buttons if you want to map to Amiga1 - Amiga2 - UP - DOWN ; after each acquired mapping, the "running led" changes state (lit-unlit-lit-unlit)
  - press in sequence the buttons AND keep LEFT direction pressed while pressing if you want to map to Amiga1 - Amiga2 - Amiga1 - Amiga2 
  - once the mapping of 4th button has been performed, your configuration will be automatically saved, and the "running led" will start blinking again

## **GENERAL TROUBLESHOOTING**

- Device not working or not recognized
  - Speaking in general, HID2AMI has been designed to be mostly able to manage every HID-compliant peripheral devices; unfortunately there is a lot of "partially / not fully / not at all"-hid-compliant-devices out there; some of them deliberately miscompliant (e.g. XboX360, ...), some of them because of poor/cheap/cloned implemenation (even a pad declaring himself being a keyboard has been found and tested ...). If you have one of them and would like having it to painlessly work with HID2AMI, you can try sending a mail to the author, together with your peripheral's HID Report dump.

- Device not responding properly
  - In rare cases, some chinese PS3-clones were found not properly initializing themselves when connected, then responding with wrong direction to analog stick: if the case happens, just unplugging and replugging the pad again should solve the situation

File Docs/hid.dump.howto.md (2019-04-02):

# **HID2AMI HOW TO SUBMIT AN HID DUMP** 

## **PREREQUISITES**

In order to submit an useful dump to the author, a minimal setup comprise:

 - A windows OS machine
 - Free USB Tree View tool [USBTREEVIEW](https://www.uwe-sieber.de/usbtreeview_e.html#download)
 - For advanced analysis: USBLyzer software (free trial can be d/loaded from [HERE](http://www.usblyzer.com/download.htm))

## **INSTRUCTIONS for USBTREEVIEW**

 - 1) Plug the peripheral device you want the HID information dumped in a free USB socket on your MS Windows PC
 - 2) Launch UsbTreeView
 - 3) In the left pane, highlight select the device you want to dump (e.g Logitech USB Wheel Mouse in the example pic below)
 - 4) Wait until the right pane is populated (fraction of seconds)
 - 5) Press Right Mouse Button (of your PC's mouse) and select "Copy Report From Here"
 - 6) Paste the result within a text file, name it (the file) something like "xxxx.Mouse.HID.dump.txt"
 - 7) Send the file to the author

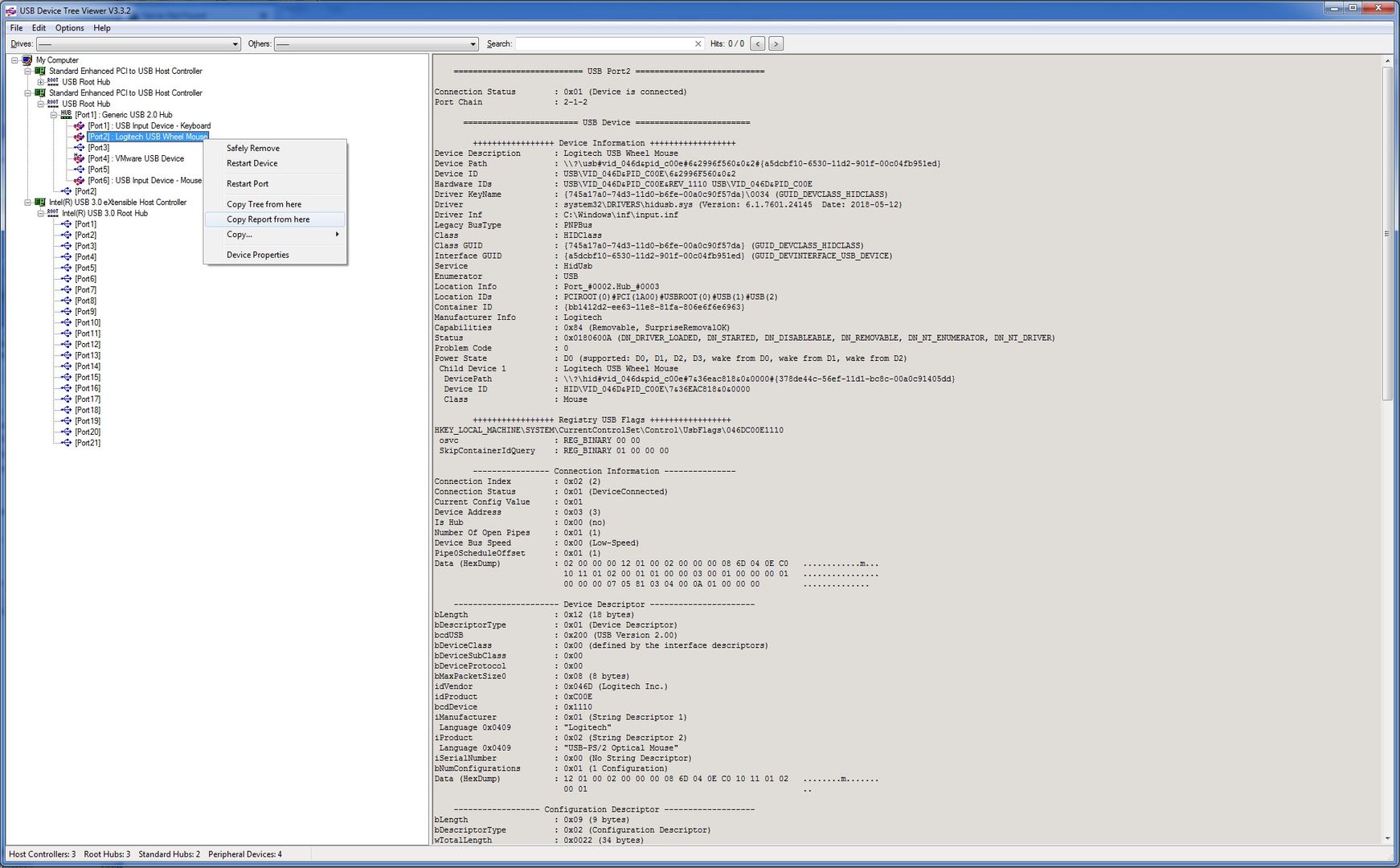
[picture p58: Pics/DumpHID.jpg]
HID2AMI
 

## **INSTRUCTIONS for USBLYZER**

 - 0) Download and install USBLyzer free trial version
 - 1) Plug the peripheral device you want the HID information dumped in a free USB socket on your MS Windows PC
 - 2) Launch USBlyzer
 - 3) In the left pane, highlight select the device you want to dump 
 - 4) Look at the "USB Properties" pane, and save its whole content to text file for submission (Figure 1 below)
 - 5) Start a capturing session:  press "Start Capture" button on the toolbar and USB analyzer software starts monitoring USB traffic going through the selected device. Leave it running for a few seconds, while interacting with your peripheral (e.g. press the buttons, move stick, move mouse - if possible do one thing at a time -)
 - 6) Stop capturing session, save the recorded data (in a file with *.ulz extension) 
 - 7) Send both the files to the author
 
 Usb Properties pane
 
 
 Sample USB Properties dump file in text format
USBPROP

Capture Pane
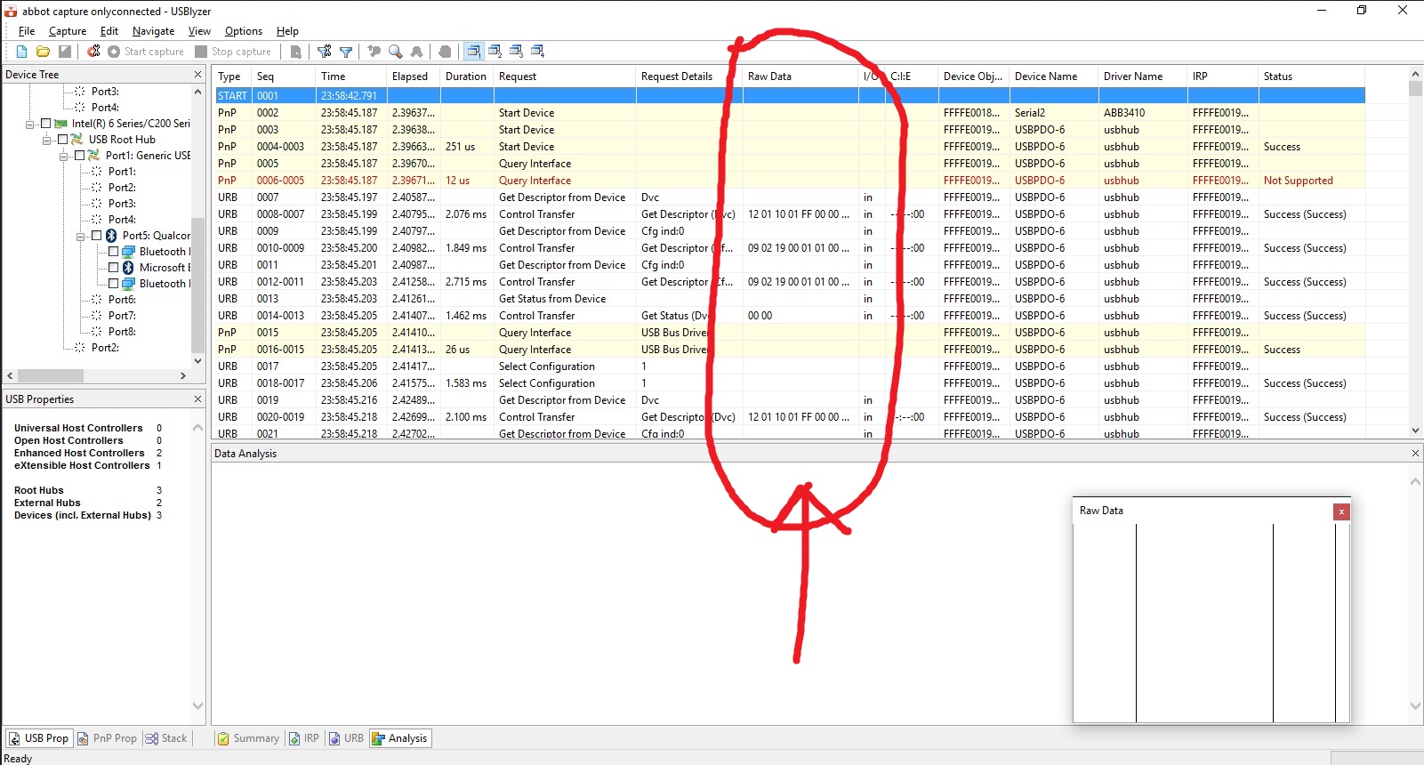
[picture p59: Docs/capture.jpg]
CAPTURE


Sample Capture "Ulz" file
ULZFILE

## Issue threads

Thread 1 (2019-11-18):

C13 Footprint

Asnivor, 2019-11-18:
Hi there,

So the 1.1.0 BOM lists C3 & C13 as 1206 10uF, but the footprint for C13 looks the same as the other 0805 caps:

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

Should C13 be a 0805 10uF, or should it be an 0805 100nF like the other caps?

Thanks!

-Asni

EmberHeavyIndustries, 2019-12-30:
Hello Asni, sorry for my late response. You spotted it right: it is a little design "bug" I did not fix among revisions. I did not notice it because I never assembled neither C3 nor C13 (they are absolutely optional, needed just in case your Amiga had a very unstable power supply circuit only). In any case, if you want to assemble them, you can safely use 0805 caps for both. Thank you for noticing me, anyway.

Closed 2021-01-25.

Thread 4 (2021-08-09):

Firmware Sources

maximevince, 2021-08-09:
Hi @EmberHeavyIndustries,

Awesome project, but I cannot seem to find the firmware source code anywhere.
Is it close-source, or is it just me that can't find it anywhere?

Thanks for the project(s)!

Cheers,
Maxime

EmberHeavyIndustries, 2021-08-09:
Hello Maxime,

I released open hardware schematics, but reserved the firmware code closed, because of too many scammers who stoled some of  my open source projects in the past, making money over my work.

I understand it could be unwise with respect to honest users (which are the most), but that's it.

If you build up the adapter, you can ask me for a (signed) copy of the firmware executable at any time.

Cheers,

maximevince, 2024-09-13:
Hi,

It took me some time, but I've build a couple of these adapters now (for my own use).
Could you send me the firmware image? (My email is in my GitHub profile, I couldn't find yours)

Thanks

EmberHeavyIndustries, 2024-09-13:
Hello, sent you an email with instructions !

Closed 2021-08-09.

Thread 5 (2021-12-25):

bootloader flashing issue on Linux

maded2, 2021-12-25:
hi,
   I've built 2 board for my own used.  Finally managed to get all the parts together for Xmas!

   But I am getting the same errors of both boards when trying to flash the bootloader.  Not sure what's wrong.

here's the logs:

```
 eddie  desktop1  ../linux-amd64  sudo ./dfu-util --list
dfu-util 0.11

Copyright 2005-2009 Weston Schmidt, Harald Welte and OpenMoko Inc.
Copyright 2010-2021 Tormod Volden and Stefan Schmidt
This program is Free Software and has ABSOLUTELY NO WARRANTY
Please report bugs to http://sourceforge.net/p/dfu-util/tickets/

Found DFU: [0483:df11] ver=2200, devnum=67, cfg=1, intf=0, path="3-1", alt=1, name="@Option Bytes  /0x1FFFF800/01*016 e", serial="STM32"
Found DFU: [0483:df11] ver=2200, devnum=67, cfg=1, intf=0, path="3-1", alt=0, name="@Internal Flash  /0x08000000/128*002Kg", serial="STM32"
```
```
 eddie  desktop1  ../linux-amd64  sudo ./dfu-util -D ~/Downloads/HID2AMIBOOTLOADER.dfu -i 0 -a 0
dfu-util 0.11

Copyright 2005-2009 Weston Schmidt, Harald Welte and OpenMoko Inc.
Copyright 2010-2021 Tormod Volden and Stefan Schmidt
This program is Free Software and has ABSOLUTELY NO WARRANTY
Please report bugs to http://sourceforge.net/p/dfu-util/tickets/

Match vendor ID from file: 0483
Match product ID from file: 0000
Multiple alternate interfaces for DfuSe file
Opening DFU capable USB device...
Device ID 0483:df11
Device DFU version 011a
Claiming USB DFU Interface...
Setting Alternate Interface #0 ...
Determining device status...
DFU state(10) = dfuERROR, status(10) = Device's firmware is corrupt. It cannot return to run-time (non-DFU) operations
Clearing status
Determining device status...
DFU state(2) = dfuIDLE, status(0) = No error condition is present
DFU mode device DFU version 011a
Device returned transfer size 2048
DfuSe interface name: "Internal Flash  "
File contains 1 DFU images
Parsing DFU image 1
Target name: HID2AMIBOOT_1.4.0
Image for alternate setting 0, (1 elements, total size = 21576)
Setting Alternate Interface #0 ...
Parsing element 1, address = 0x08000000, size = 21568
Erase   	[                         ]   0%            0 bytesdfu-util: dfuse_download: libusb_control_transfer returned -7 (LIBUSB_ERROR_TIMEOUT)
dfu-util: Error during special command "ERASE_PAGE" download
```

so I tried adding the unprotect:
```

 eddie  desktop1  ../linux-amd64  sudo ./dfu-util -D ~/Downloads/HID2AMIBOOTLOADER.dfu -i 0 -a 0 -s 0:force:unprotect
dfu-util 0.11

Copyright 2005-2009 Weston Schmidt, Harald Welte and OpenMoko Inc.
Copyright 2010-2021 Tormod Volden and Stefan Schmidt
This program is Free Software and has ABSOLUTELY NO WARRANTY
Please report bugs to http://sourceforge.net/p/dfu-util/tickets/

Match vendor ID from file: 0483
Match product ID from file: 0000
Multiple alternate interfaces for DfuSe file
Opening DFU capable USB device...
Device ID 0483:df11
Device DFU version 011a
Claiming USB DFU Interface...
Setting Alternate Interface #0 ...
Determining device status...
DFU state(10) = dfuERROR, status(15) = Device stalled an unexpected request
Clearing status
Determining device status...
DFU state(2) = dfuIDLE, status(0) = No error condition is present
DFU mode device DFU version 011a
Device returned transfer size 2048
DfuSe interface name: "Internal Flash  "
Device disconnects, erases flash and resets now
```

but I still get the same error.

thanks in advance for your help.

eddie

maded2, 2021-12-25:
I've managed to flash the bootloader in Windows, looks like linux dfu-util can not handle the totally blank STM32 chip.

Closed 2021-12-25.

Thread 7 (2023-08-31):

Unable to enter DFU mode

jsanpe, 2023-08-31:
I recently finished assembling a HID2AMI and I am currently in the phase of flashing the firmware. Following the instructions of the guide (for Linux) won't lead to a dfu device recognized by the system.

While it's very likely to be a problem with the soldering of the components I wanted to be sure that DFU mode actually comes pre-installed in the  STM32F103RCT6 system ram. According to https://community.st.com/t5/embedded-software-mcus/bootloader-dfu-stm32f103/td-p/159027 this is NOT the case. I don't have a lot of experience with STM32s, what's the general experience with this particular MCU? What would be an alternative to get the .dfu files flashed?

Thanks for your help!

jsanpe, 2023-09-01:
Seems that the MCU to be used is the STM32F105 (not F103). Closing the issue.

Closed 2023-09-01.

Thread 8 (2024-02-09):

Detached Atari keyboard (MegaSTE/TT) doesn't like HID2AMI very much

mikrosk, 2024-02-09:
I have bought two devices (pre-programmed to Atari mode) in "HID2AMI - 8th batch" on amibay. So I believe I'm running a fairly recent hardware and software. They work well, they recognise all of my USB mice, cool.

However I have noticed one oddity: when connected to my MegaSTE's or TT's external keyboard (what is my primary use case as their DSUB9 ports are easily accessible) upon boot, the keyboard is totally messed up in the desktop (i.e. keys are interpreted wrongly, if at all). Mouse still works all right.

The only fix to it is:
- disconnect the mouse
- disconnect the keyboard
- reconnect the keyboard
- reconnect the mouse

If I keep the mouse connected, it doesn't help. If I unplug just the mouse, it doesn't help. Also, when I reset the Atari, the problem is back. So it seems to be somehow related to IKBD reset or something like that.

I tested it also on my STE, there's no such issue. Also I tested it on both Mega STE (8 MHz) and TT (48 MHz) so it's not related to TOS or CPU speed.

If there's a way to help you out with debugging, please let me know.

mikrosk, 2024-02-11:
I tested it on my Falcon today: same issue.

EmberHeavyIndustries, 2024-06-30:
Uh, sorry I missed this one. Reading now...
Unfortunately I only own an STE from the Atari world, so i can't debug in deep.
Maybe it could be related to the wheelmouse protocol (for the Amiga), which need some esotic interaction with mouse port pins.

Would you please send me an email at EmberHeavyIndustries@gmail.com with your adapter codes, so I can set up a modified version with that protocol disabled ? (useless for Atari).

Closed 2024-06-30.

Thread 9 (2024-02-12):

Which controllers of the STM32F1xx series are allowed to be used?

alex-nemo, 2024-02-12:
Which controllers of the STM32F1xx series are allowed to be used?
Is it permissible to use STM32F1xx controllers in the LQFP-64 package. For example: STM32F103RBT6 [LQFP-64], STM32F103RCT6 [LQFP-64], STM32F103RET6 [LQFP-64].
Can I remake the board for STM32F1xx in the LQFP-48 package.  For example: STM32F103C8T6 [LQFP-48], STM32F103CBT6 [LQFP-48].

EmberHeavyIndustries, 2024-04-05:
You can pin-to-pin swap F105RBT6 or F105RCT6 (the latter doubles the flash internal memory)
You cal also swap with F205RXT6 (pointless because they are more expensive than F105)
You can't swap with F103, because they don't support USB HOST functionality which is needed

Closed 2024-04-05.

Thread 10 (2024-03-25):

Commodore 64 GEOS - 1531 mouse

celso, 2024-03-25:
Would it be possible to support the 1351 analog mouse on the C64/128?

https://www.c64-wiki.com/wiki/Mouse

https://en.wikipedia.org/wiki/Commodore_1351

EmberHeavyIndustries, 2024-04-05:
Not with the current hardware, sorry. As the name implies, it is an analog device; hid2ami is fully digital.

Closed 2024-04-05.

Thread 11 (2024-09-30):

Hori fighting stick mini ps4

morch-uk, 2024-09-30:
on either ps3 or ps4 mode - it does work but I'm having issues remapping buttons, using the first 4 buttons as seen by my windows pc and pressing down; it doesn't do anything it still flashes rather than stopping

any recommendations

morch-uk, 2024-10-03:
reflashed firmware and it started to work again must have had a bad saved config

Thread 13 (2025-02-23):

Suggestion: helpful LED Blinking at startup

shprotru, 2025-02-23:
I have assembled the board of version 2, and there is difficult to diagnose, am I correctly firmwared it or not. It wan't to detects with . I wish to ask you to add some diagnose blinking with green LED on startup.
Like:
1. mode APP(BOOT0 with 1-2 joined pins and PA9BOOT with 1-2 joined pins): green led blinks 2 times at start with pause in 1 second and 1 second timeout of each blinks.
2. mode program DFU(BOOT0 with 1-2 joined pins and PA9BOOT with 2-3 joined pins): green led blinks 1 time at startup with 1 second timeout.
3. mode system DFU(BOOT0 with 2-3 joined pins and PA9BOOT with 2-3 joined pins): impossible to implement, as I understand it.

Would be great to diagnose, am I ready for activation, or make some mistakes on assembly or flashing step.

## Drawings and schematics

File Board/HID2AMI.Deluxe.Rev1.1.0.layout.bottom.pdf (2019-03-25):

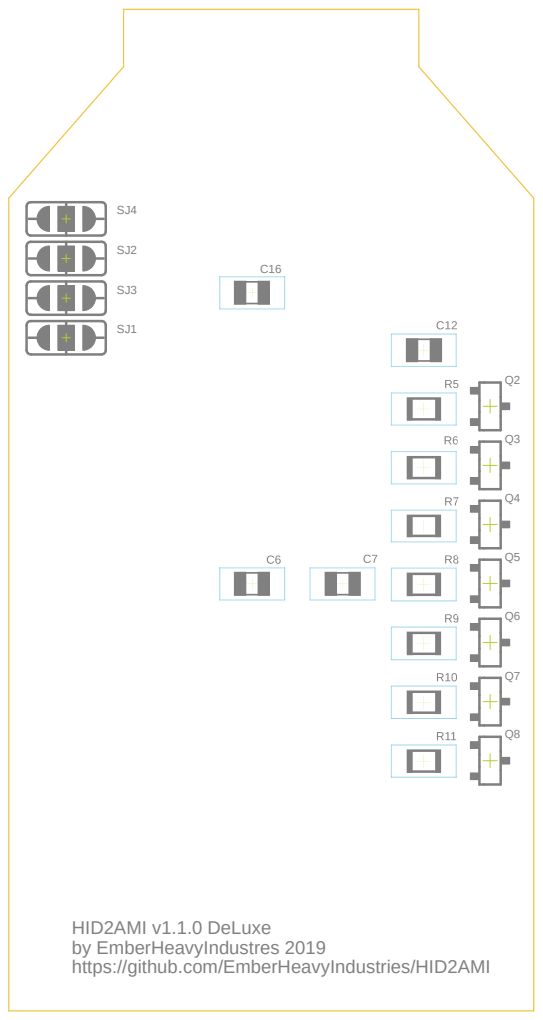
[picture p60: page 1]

HID2AMI v1.1.0 DeLuxe
by EmberHeavyIndustres 2019
https://github.com/EmberHeavyIndustries/HID2AMI

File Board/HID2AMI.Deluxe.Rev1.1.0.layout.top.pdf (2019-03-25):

F09

# X2JP2

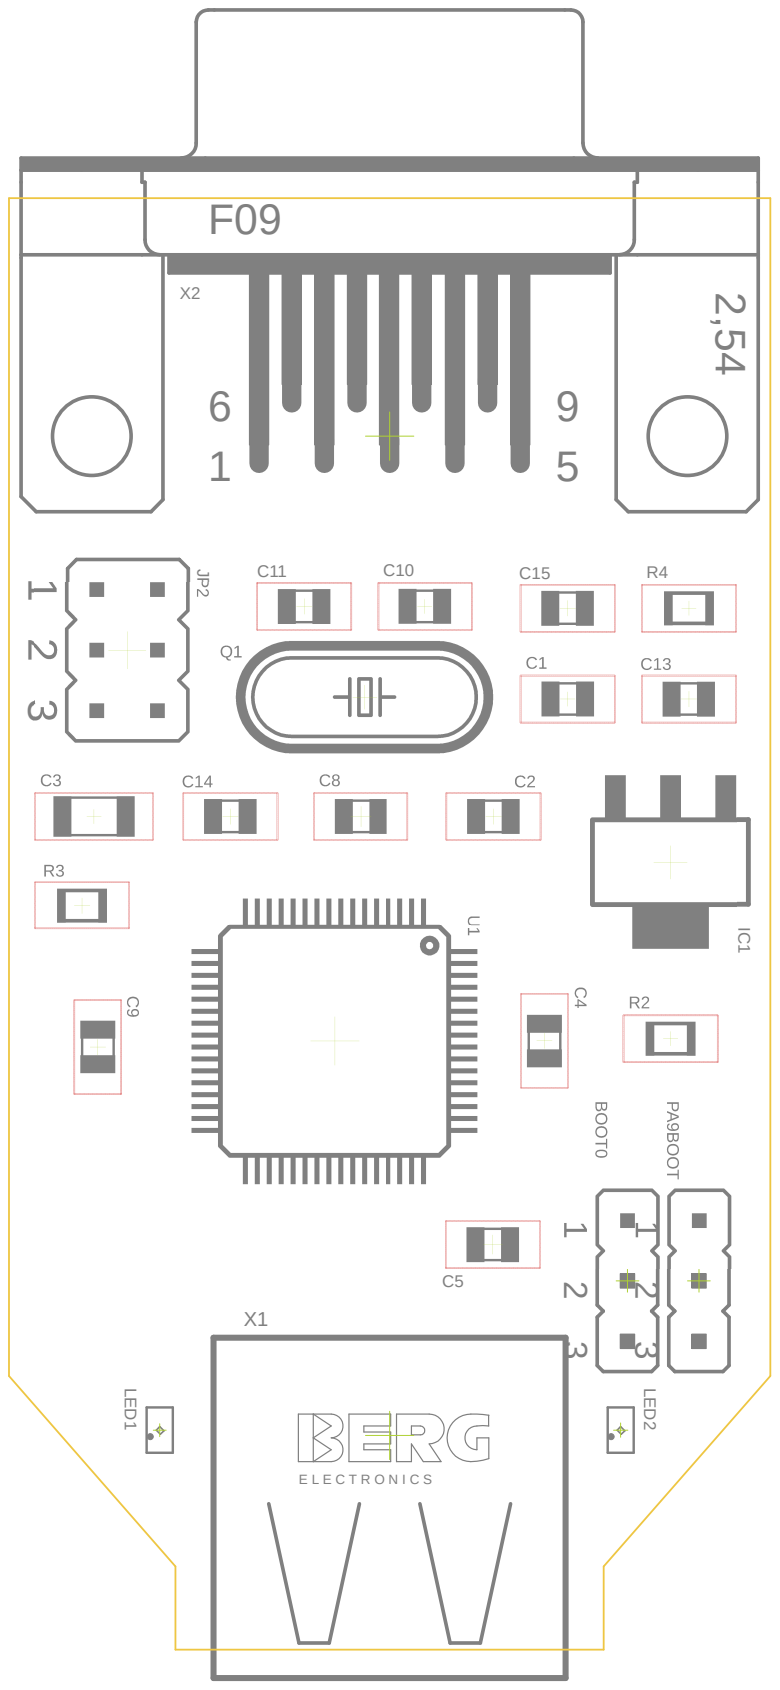
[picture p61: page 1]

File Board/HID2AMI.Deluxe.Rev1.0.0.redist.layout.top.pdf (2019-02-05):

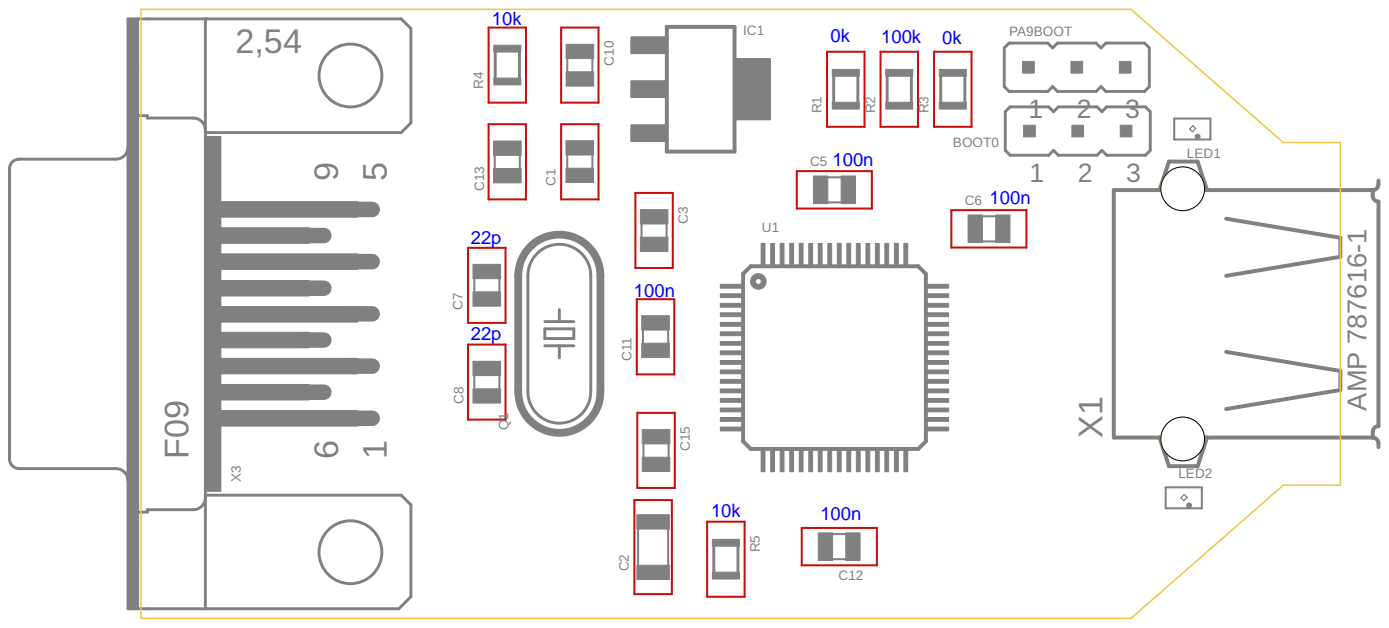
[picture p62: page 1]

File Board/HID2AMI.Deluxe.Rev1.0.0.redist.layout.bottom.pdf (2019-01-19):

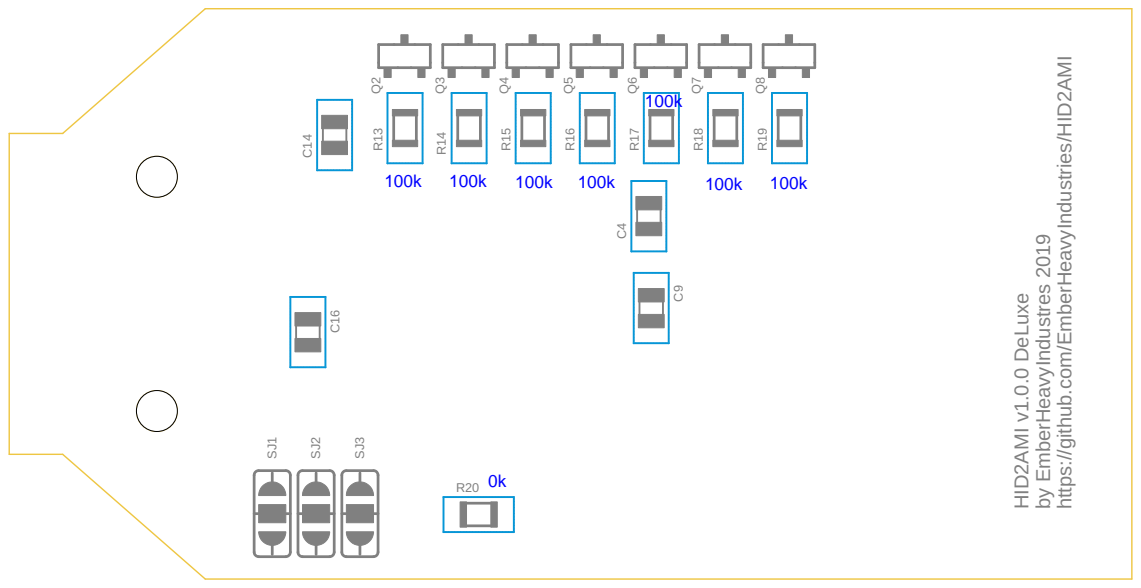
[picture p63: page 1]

HID2AMI v1.0.0 DeLuxe by EmberHeavyIndustres 2019 https:/ github.com/EmberHeavyIndustries/HID2AMI C16 C4 C14 C9 SJ1 SJ2 SJ3 Q2 Q3 Q4 Q5 Q6 Q7 Q8 R13 R14 R15 R16 R17 R18 R19 R20

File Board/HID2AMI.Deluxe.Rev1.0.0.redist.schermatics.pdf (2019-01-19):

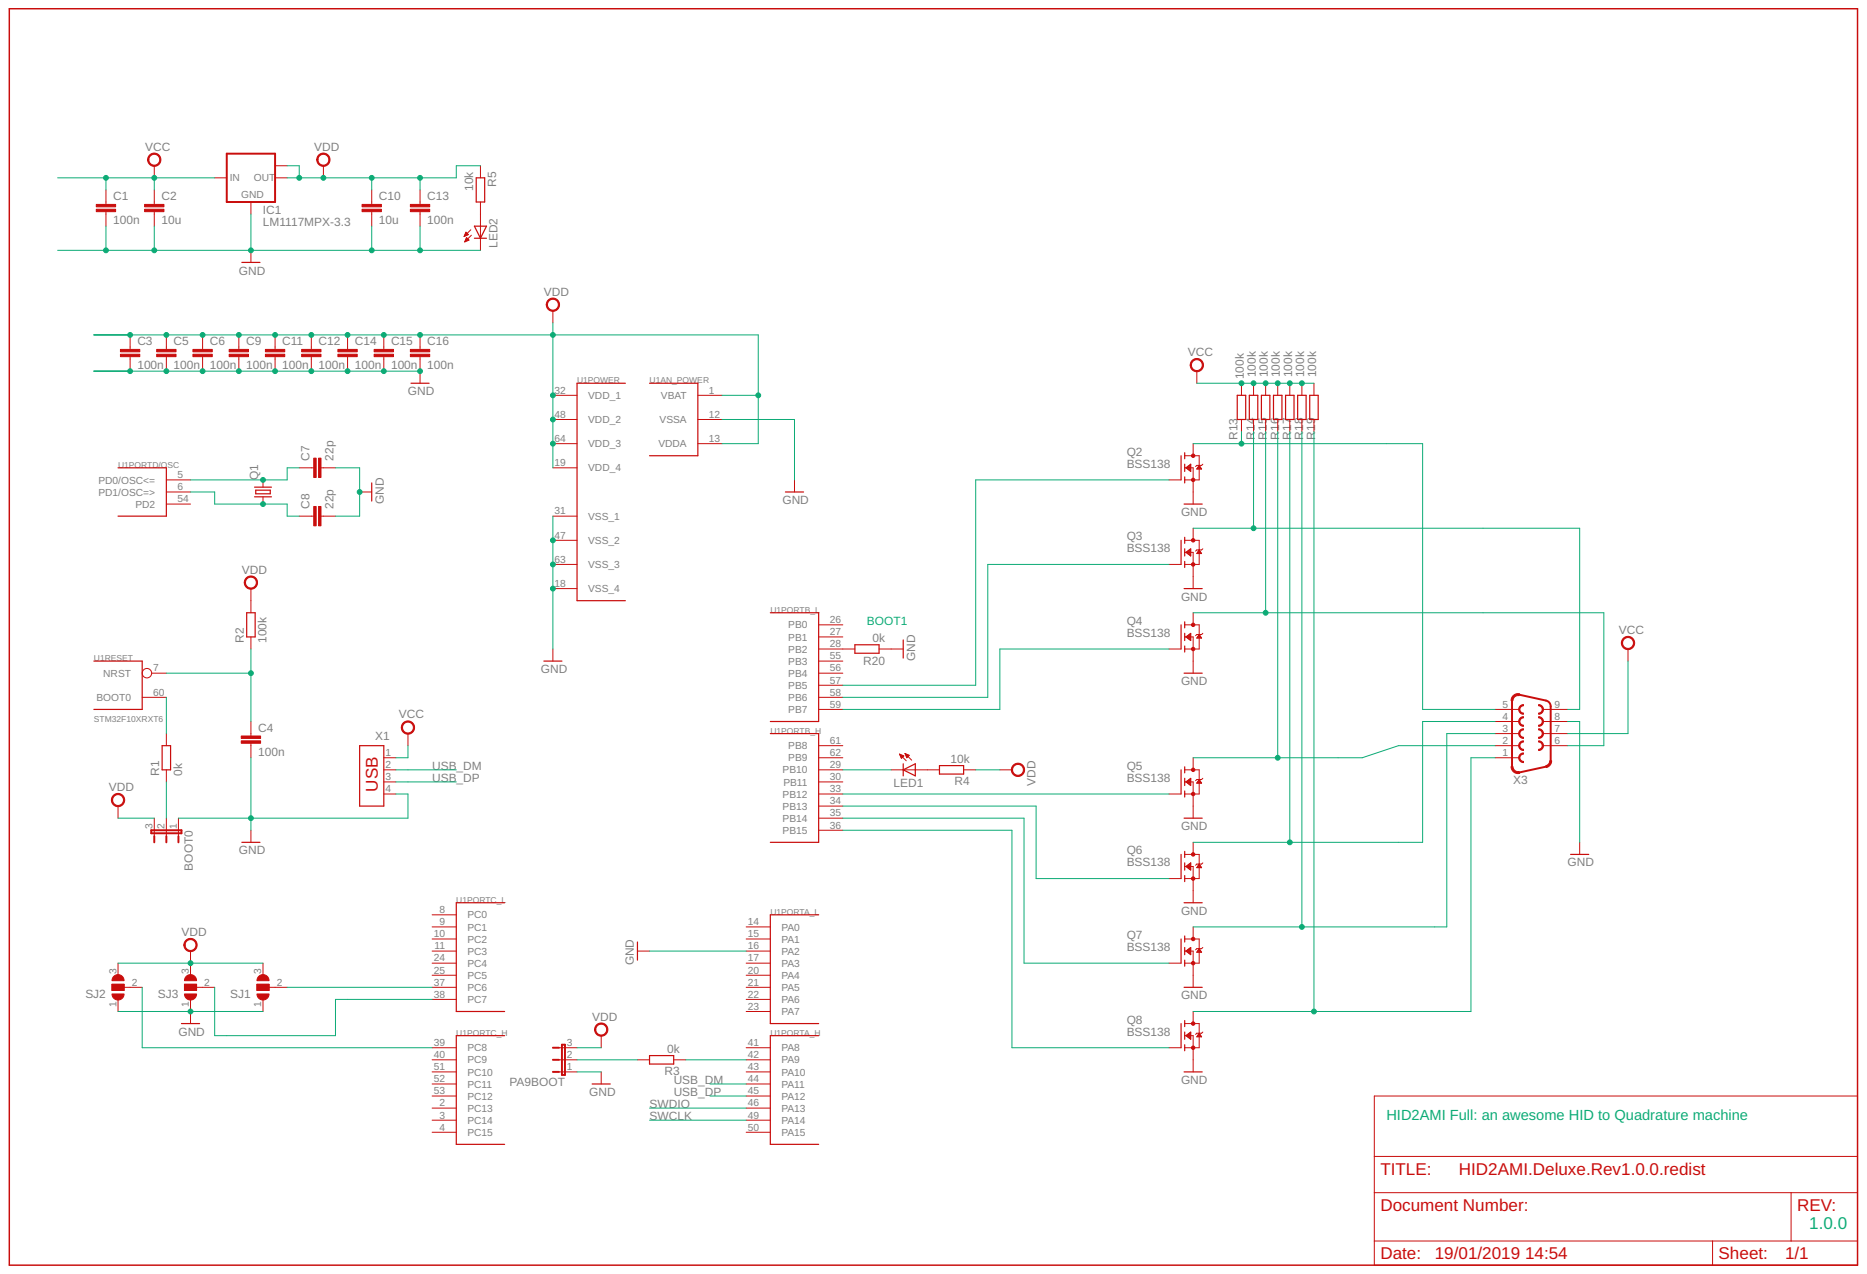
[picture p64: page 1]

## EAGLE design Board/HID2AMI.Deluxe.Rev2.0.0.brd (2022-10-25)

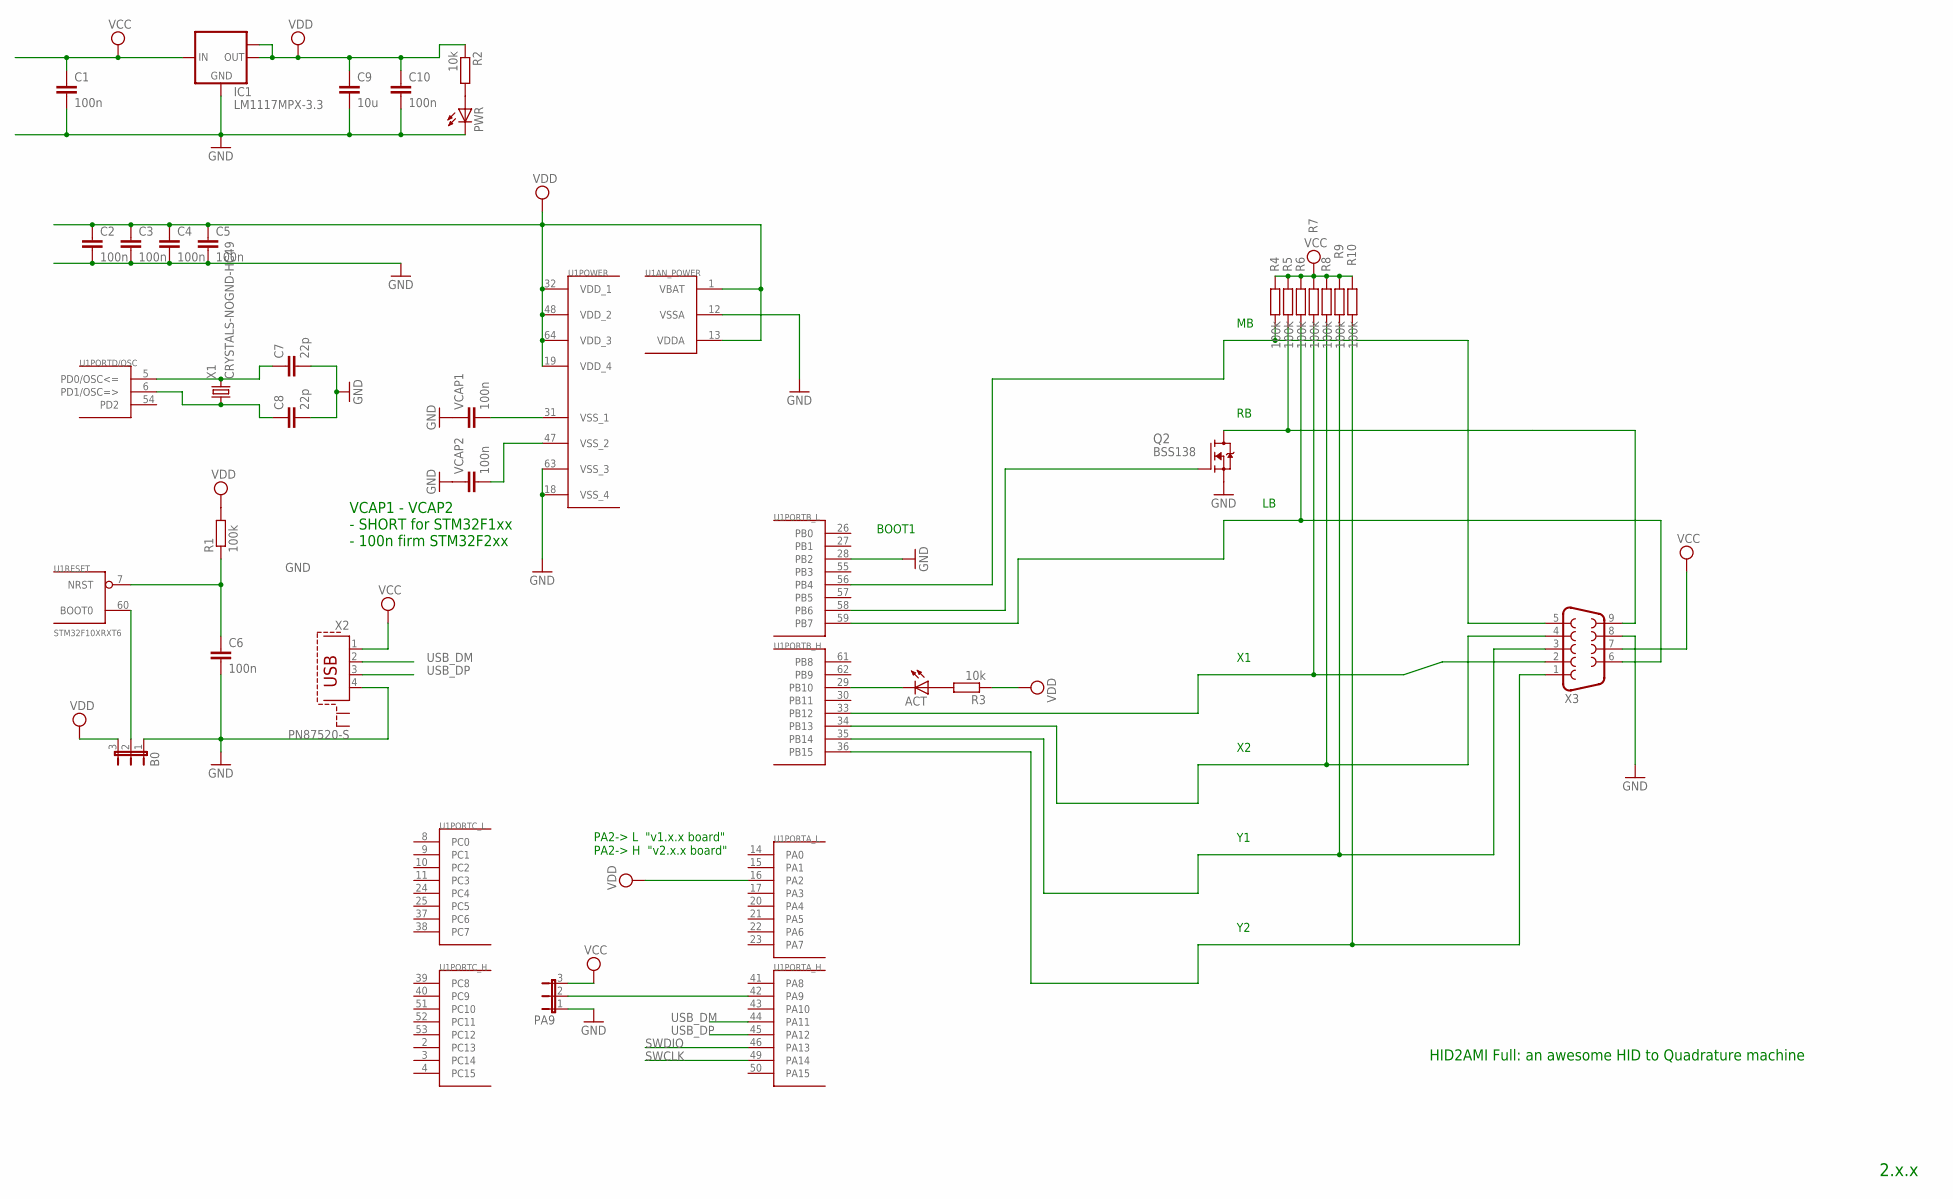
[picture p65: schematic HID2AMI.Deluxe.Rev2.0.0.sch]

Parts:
ACT: LEDSML0805; SML0805
B0: JP2E; JP2
C1, C2, C3, C4, C5, C6, C10: 100n; C0805
C7, C8: 22p; C0805
C9: 10u; C0805
IC1: LM1117MPX-3.3; SOT223
PA9: JP2E; JP2
PWR: LEDSML0805; SML0805
Q2: BSS138; SOT23
R1, R4, R5, R6, R7, R8, R9, R10: 100k; M0805
R2, R3: 10k; M0805
U1: STM32F10XRXT6; TQFP64
VCAP1, VCAP2: 100n; C0805
X1: CRYSTALS-NOGND-HC49; HC49
X2: PN87520-S
X3: F09HP

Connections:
ACT: R7.2, U1.33 (PB12), X3.2
GND: B0.1, C1.2, C2.2, C3.2, C4.2, C5.2, C6.2, C7.2, C8.2, C9.2, C10.2, IC1.1 (GND), PA9.1, PWR.C, Q2.2 (S), U1.12 (VSSA), U1.18 (VSS_4), U1.28 (PB2), U1.63 (VSS_3), VCAP1.1, VCAP2.1, X2.4, X3.8
unnamed: C7.1, U1.5 (PD0/OSC<=), X1.2
unnamed: C8.1, U1.6 (PD1/OSC=>), X1.1
unnamed: B0.2, U1.60 (BOOT0)
unnamed: U1.31 (VSS_1), VCAP1.2
unnamed: PA9.2, U1.42 (PA9)
unnamed: U1.47 (VSS_2), VCAP2.2
unnamed: ACT.A, R3.2
unnamed: ACT.C, U1.29 (PB10)
unnamed: PWR.A, R2.2
unnamed: R4.2, U1.56 (PB4), X3.5
unnamed: Q2.1 (G), U1.58 (PB6)
unnamed: R6.2, U1.59 (PB7), X3.6
unnamed: Q2.3 (D), R5.2, X3.9
unnamed: R8.2, U1.34 (PB13), X3.4
unnamed: R9.2, U1.35 (PB14), X3.3
unnamed: R10.2, U1.36 (PB15), X3.1
NRST: C6.1, R1.1, U1.7 (NRST)
SWCLK: U1.49 (PA14)
SWDIO: U1.46 (PA13)
USB_DM: U1.44 (PA11), X2.2
USB_DP: U1.45 (PA12), X2.3
VCC: C1.1, IC1.3 (IN), PA9.3, R4.1, R5.1, R6.1, R7.1, R8.1, R9.1, R10.1, X2.1, X3.7
VDD: B0.3, C2.1, C3.1, C4.1, C5.1, C9.1, C10.1, IC1.2 (OUT), IC1.TAB (OUT1), R1.2, R2.1, R3.1, U1.1 (VBAT), U1.13 (VDDA), U1.16 (PA2), U1.19 (VDD_4), U1.32 (VDD_1), U1.48 (VDD_2), U1.64 (VDD_3)

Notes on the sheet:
2.x.x
HID2AMI Full: an awesome HID to Quadrature machine
PA2-> L "v1.x.x board" PA2-> H "v2.x.x board"
BOOT1
VCAP1 - VCAP2 - SHORT for STM32F1xx - 100n firm STM32F2xx

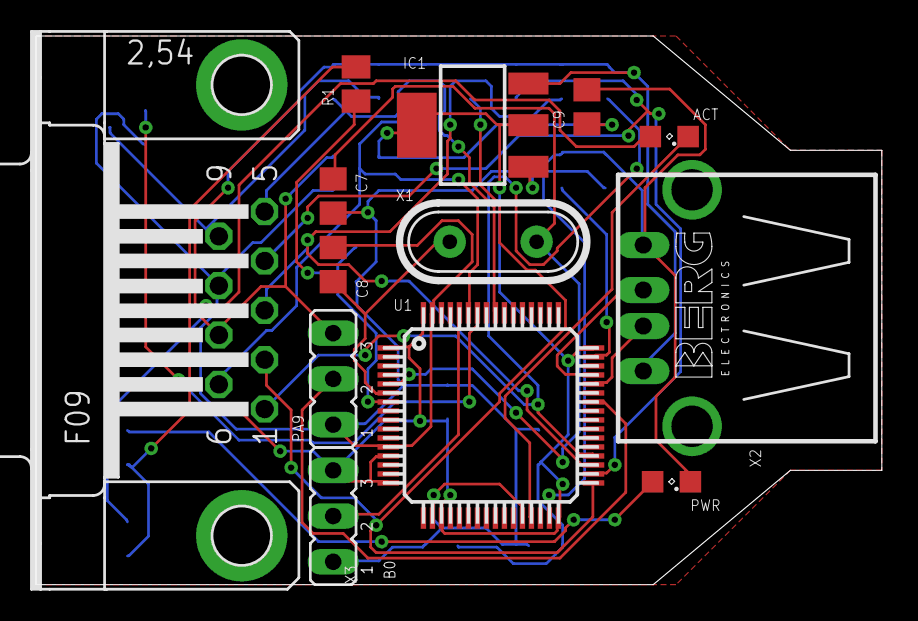
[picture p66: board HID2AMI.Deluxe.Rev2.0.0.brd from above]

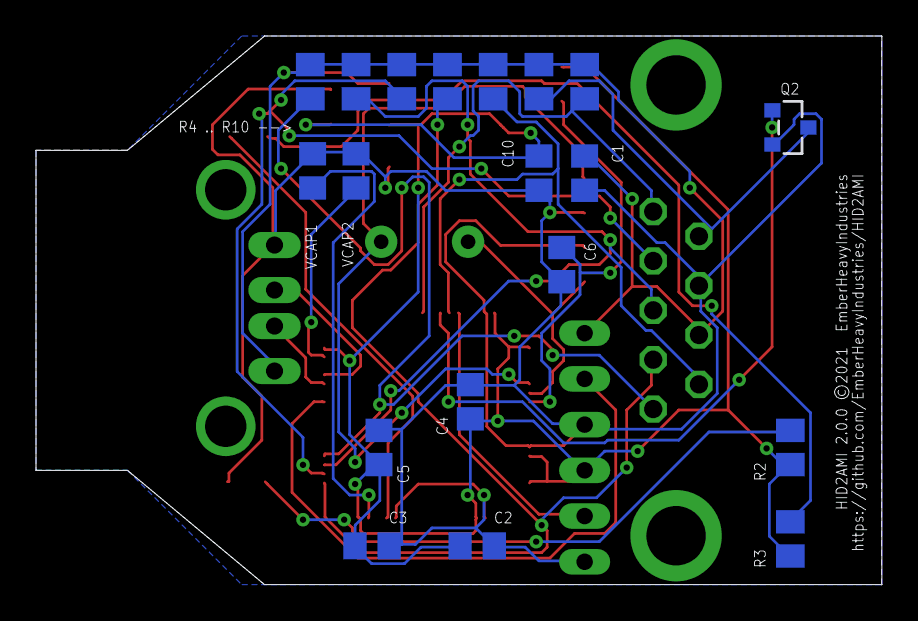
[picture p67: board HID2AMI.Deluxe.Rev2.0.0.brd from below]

Board: 2 copper layers, 47.0 x 30.5 mm, 32 parts (19 on the bottom side), 23 nets.

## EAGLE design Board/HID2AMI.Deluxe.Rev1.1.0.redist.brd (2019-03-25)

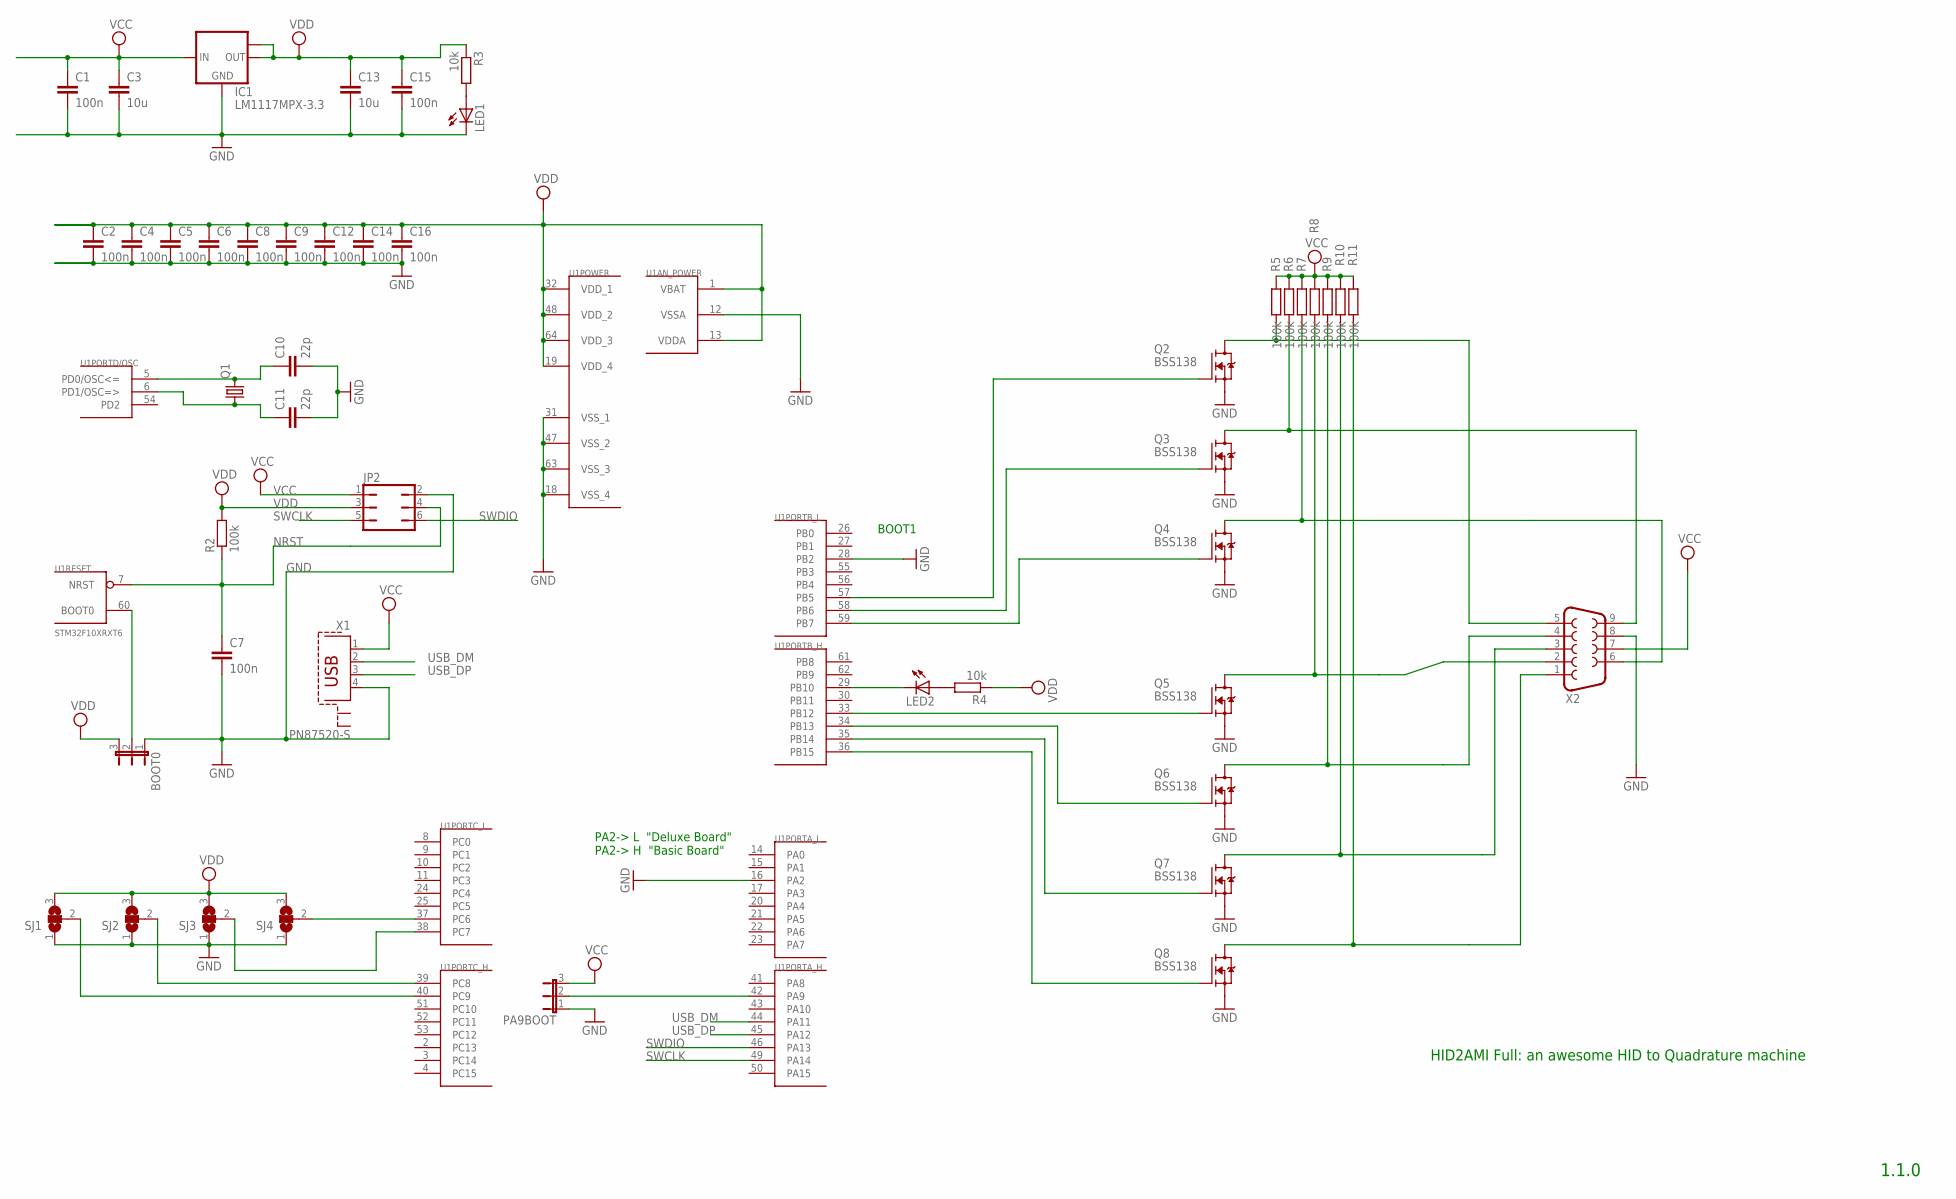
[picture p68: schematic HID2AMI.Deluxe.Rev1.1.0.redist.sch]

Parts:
BOOT0: JP2E; JP2
C1, C2, C4, C5, C6, C7, C8, C9, C12, C14, C15, C16: 100n; C0805
C3: 10u; C1206
C10, C11: 22p; C0805
C13: 10u; C0805
IC1: LM1117MPX-3.3; SOT223
JP2: JP3Q
LED1, LED2: LEDSML0805; SML0805
PA9BOOT: JP2E; JP2
Q1: CRYSTALHC49S; HC49/S
Q2, Q3, Q4, Q5, Q6, Q7, Q8: BSS138; SOT23
R2, R5, R6, R7, R8, R9, R10, R11: 100k; M0805
R3, R4: 10k; M0805
SJ1, SJ2, SJ3, SJ4: SJ2W; SJ_2
U1: STM32F10XRXT6; TQFP64
X1: PN87520-S
X2: F09HP

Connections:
GND: BOOT0.1, C1.2, C2.2, C3.2, C4.2, C5.2, C6.2, C7.2, C8.2, C9.2, C10.2, C11.2, C12.2, C13.2, C14.2, C15.2, C16.2, IC1.1 (GND), JP2.2, LED1.C, PA9BOOT.1, Q2.2 (S), Q3.2 (S), Q4.2 (S), Q5.2 (S), Q6.2 (S), Q7.2 (S), Q8.2 (S), SJ1.1, SJ2.1, SJ3.1, SJ4.1, U1.12 (VSSA), U1.16 (PA2), U1.18 (VSS_4), U1.28 (PB2), U1.31 (VSS_1), U1.47 (VSS_2), U1.63 (VSS_3), X1.4, X2.8
unnamed: C10.1, Q1.2, U1.5 (PD0/OSC<=)
unnamed: C11.1, Q1.1, U1.6 (PD1/OSC=>)
unnamed: BOOT0.2, U1.60 (BOOT0)
unnamed: PA9BOOT.2, U1.42 (PA9)
unnamed: SJ1.2, U1.40 (PC9)
unnamed: LED2.A, R4.2
unnamed: LED2.C, U1.29 (PB10)
unnamed: SJ4.2, U1.37 (PC6)
unnamed: SJ3.2, U1.38 (PC7)
unnamed: SJ2.2, U1.39 (PC8)
unnamed: LED1.A, R3.2
unnamed: Q2.1 (G), U1.57 (PB5)
unnamed: Q3.1 (G), U1.58 (PB6)
unnamed: Q4.1 (G), U1.59 (PB7)
unnamed: Q5.1 (G), U1.33 (PB12)
unnamed: Q6.1 (G), U1.34 (PB13)
unnamed: Q7.1 (G), U1.35 (PB14)
unnamed: Q8.1 (G), U1.36 (PB15)
unnamed: Q2.3 (D), R5.2, X2.5
unnamed: Q3.3 (D), R6.2, X2.9
unnamed: Q4.3 (D), R7.2, X2.6
unnamed: Q5.3 (D), R8.2, X2.2
unnamed: Q6.3 (D), R9.2, X2.4
unnamed: Q7.3 (D), R10.2, X2.3
unnamed: Q8.3 (D), R11.2, X2.1
NRST: C7.1, JP2.4, R2.1, U1.7 (NRST)
SWCLK: JP2.5, U1.49 (PA14)
SWDIO: JP2.6, U1.46 (PA13)
USB_DM: U1.44 (PA11), X1.2
USB_DP: U1.45 (PA12), X1.3
VCC: C1.1, C3.1, IC1.3 (IN), JP2.1, PA9BOOT.3, R5.1, R6.1, R7.1, R8.1, R9.1, R10.1, R11.1, X1.1, X2.7
VDD: BOOT0.3, C2.1, C4.1, C5.1, C6.1, C8.1, C9.1, C12.1, C13.1, C14.1, C15.1, C16.1, IC1.2 (OUT), IC1.TAB (OUT1), JP2.3, R2.2, R3.1, R4.1, SJ1.3, SJ2.3, SJ3.3, SJ4.3, U1.1 (VBAT), U1.13 (VDDA), U1.19 (VDD_4), U1.32 (VDD_1), U1.48 (VDD_2), U1.64 (VDD_3)

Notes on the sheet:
1.1.0
HID2AMI Full: an awesome HID to Quadrature machine
PA2-> L "Deluxe Board" PA2-> H "Basic Board"
BOOT1

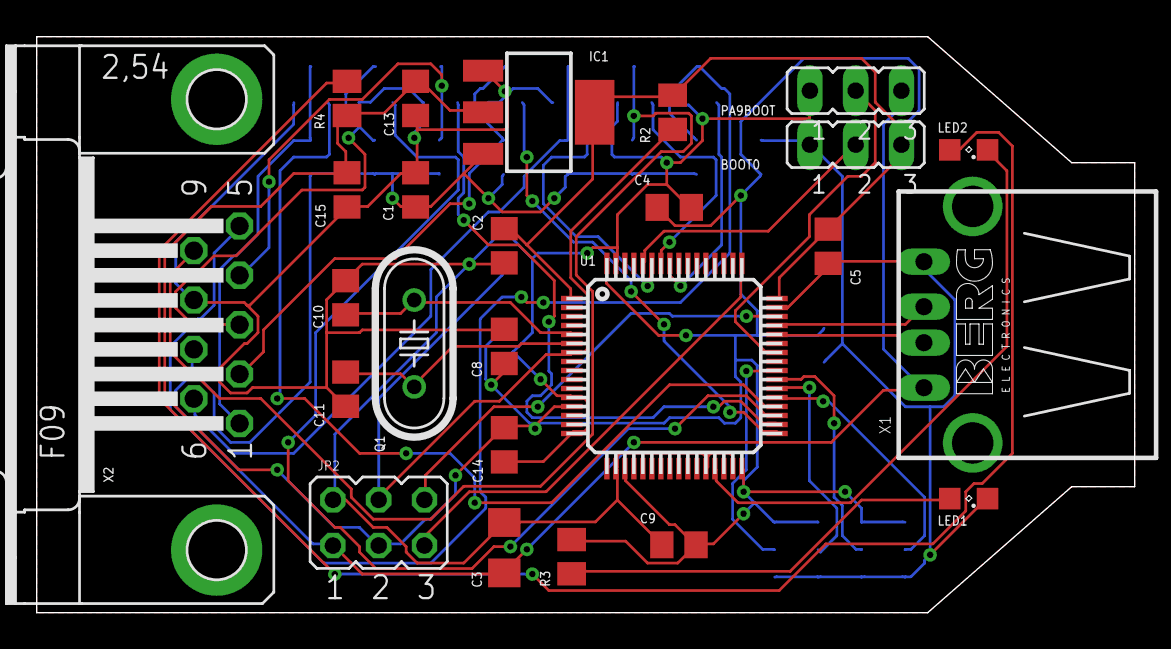
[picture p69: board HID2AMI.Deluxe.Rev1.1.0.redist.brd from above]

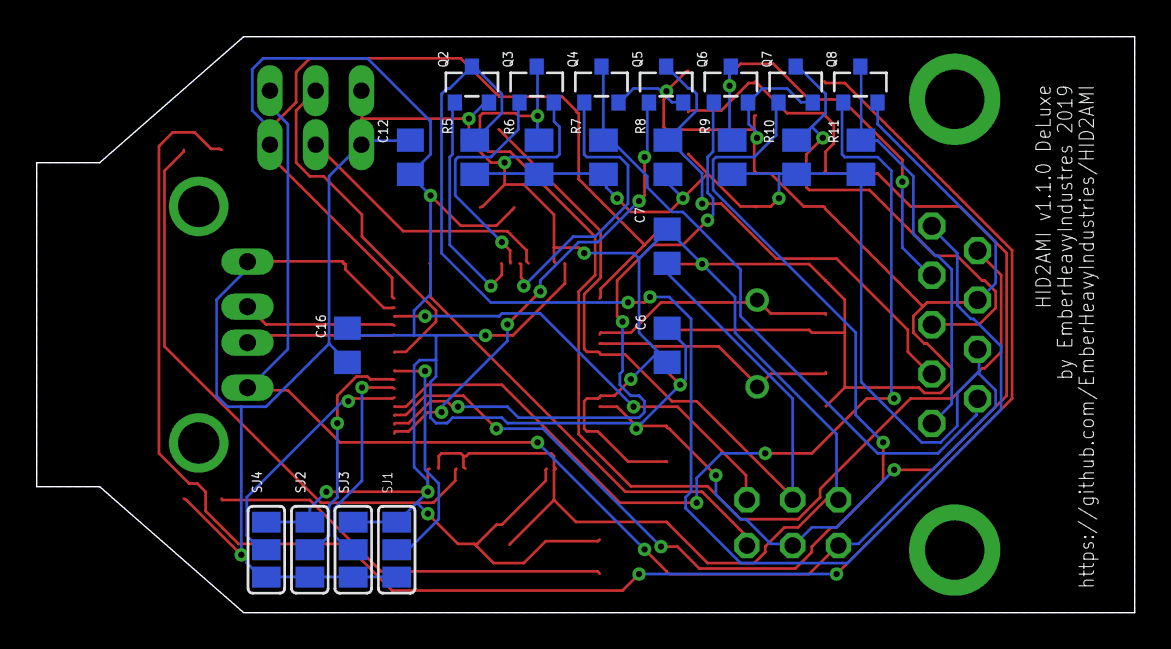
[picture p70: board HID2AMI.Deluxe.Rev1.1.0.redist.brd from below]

Board: 2 copper layers, 61.0 x 32.0 mm, 47 parts (22 on the bottom side), 33 nets.

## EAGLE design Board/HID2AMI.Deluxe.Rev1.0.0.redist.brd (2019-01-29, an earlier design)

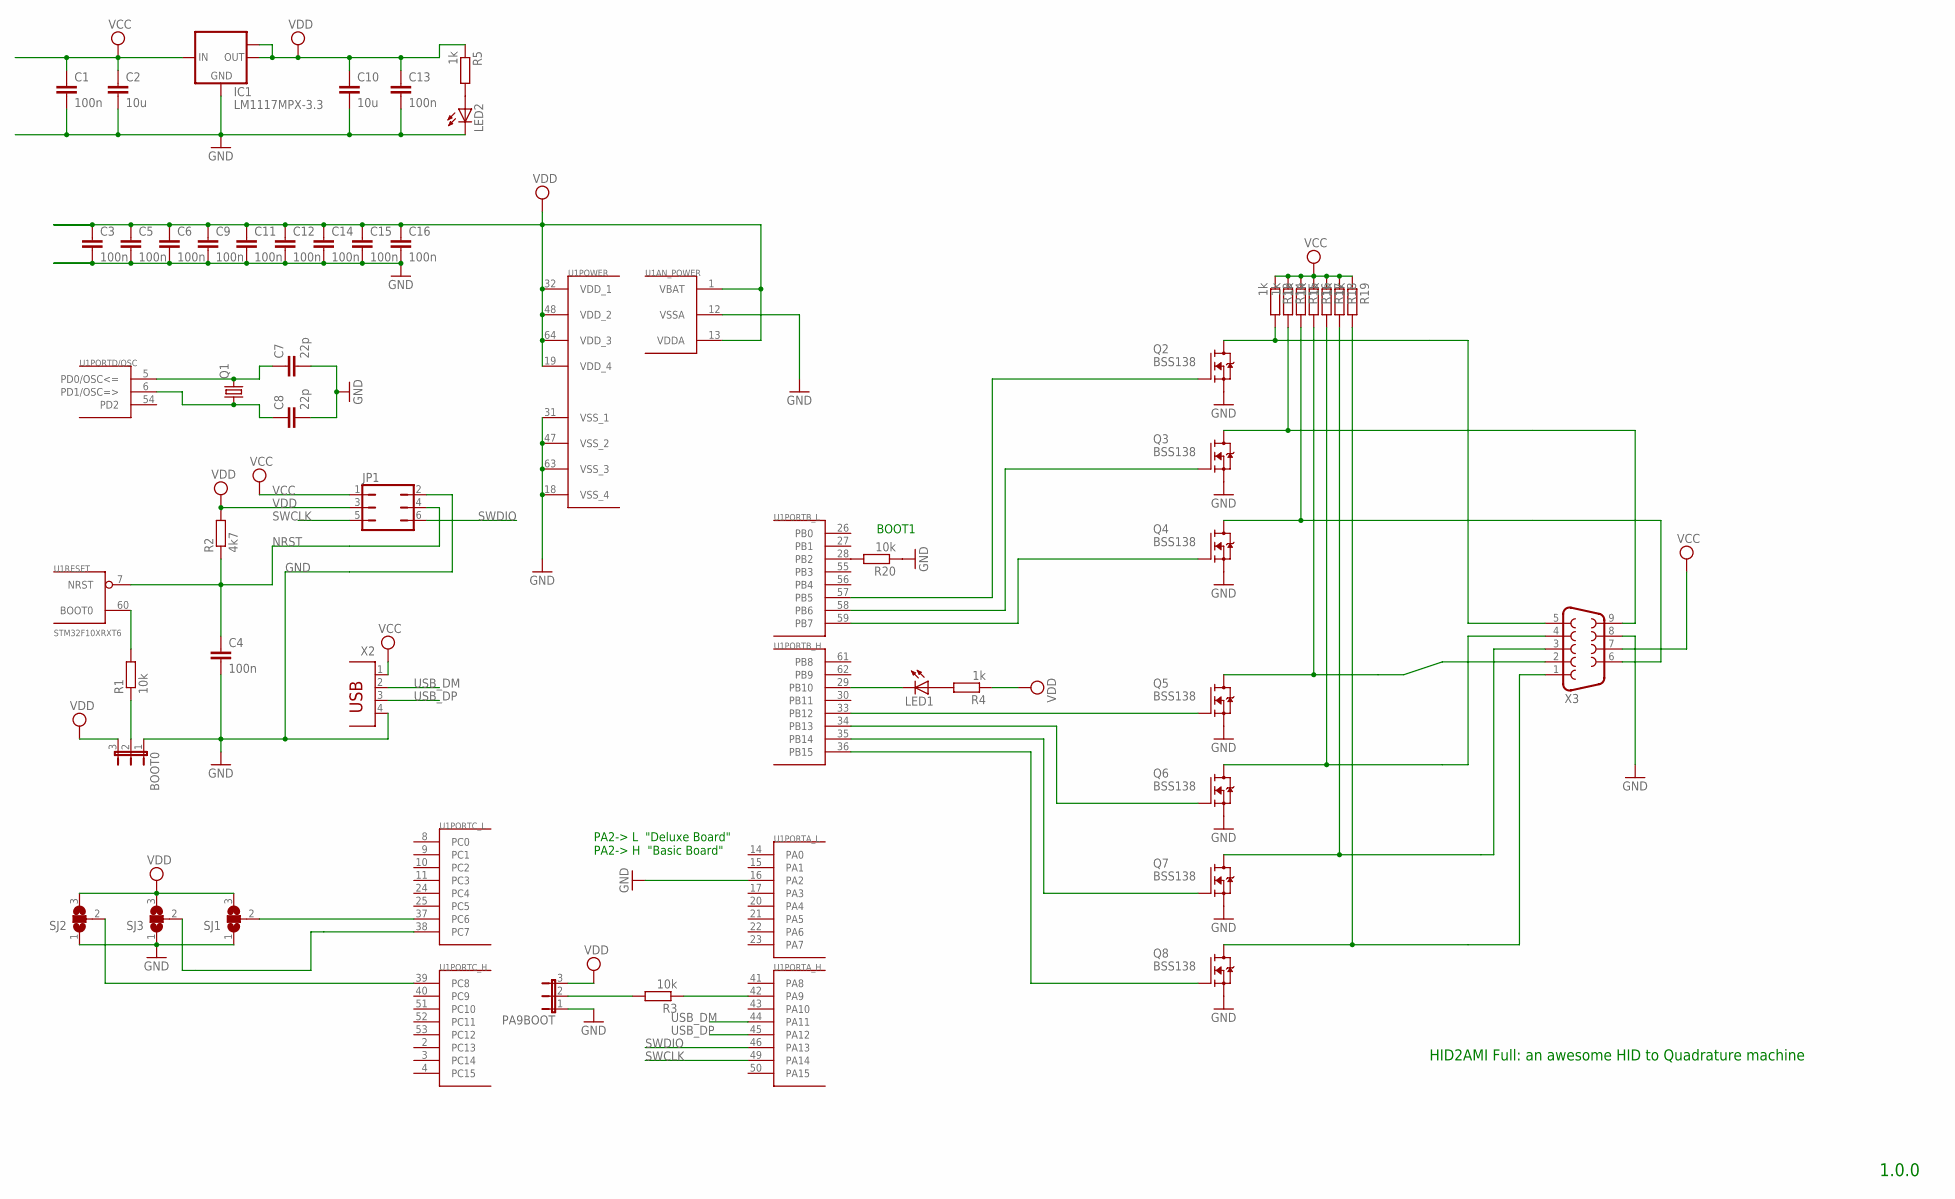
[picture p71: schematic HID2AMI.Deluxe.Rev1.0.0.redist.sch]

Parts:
BOOT0: JP2E; JP2
C1, C3, C4, C5, C6, C9, C11, C12, C13, C14, C15, C16: 100n; C0805
C2: 10u; C1206
C7, C8: 22p; C0805
C10: 10u; C0805
IC1: LM1117MPX-3.3; SOT223
JP1: JP3Q
LED1, LED2: LEDSML0805; SML0805
PA9BOOT: JP2E; JP2
Q1: CRYSTALHC49S; HC49/S
Q2, Q3, Q4, Q5, Q6, Q7, Q8: BSS138; SOT23
R1, R3, R20: 10k; M0805
R2: 4k7; M0805
R4, R5, R13, R14, R15, R16, R17, R18, R19: 1k; M0805
SJ1, SJ2, SJ3: SJ2W; SJ_2
U1: STM32F10XRXT6; TQFP64
X2: PN87520
X3: F09HP

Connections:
GND: BOOT0.1, C1.2, C2.2, C3.2, C4.2, C5.2, C6.2, C7.2, C8.2, C9.2, C10.2, C11.2, C12.2, C13.2, C14.2, C15.2, C16.2, IC1.1 (GND), JP1.2, LED2.C, PA9BOOT.1, Q2.2 (S), Q3.2 (S), Q4.2 (S), Q5.2 (S), Q6.2 (S), Q7.2 (S), Q8.2 (S), R20.1, SJ1.1, SJ2.1, SJ3.1, U1.12 (VSSA), U1.16 (PA2), U1.18 (VSS_4), U1.31 (VSS_1), U1.47 (VSS_2), U1.63 (VSS_3), X2.4, X3.8
unnamed: C7.1, Q1.2, U1.5 (PD0/OSC<=)
unnamed: C8.1, Q1.1, U1.6 (PD1/OSC=>)
unnamed: R1.2, U1.60 (BOOT0)
unnamed: BOOT0.2, R1.1
unnamed: PA9BOOT.2, R3.2
unnamed: R3.1, U1.42 (PA9)
unnamed: LED1.A, R4.2
unnamed: LED1.C, U1.29 (PB10)
unnamed: SJ1.2, U1.37 (PC6)
unnamed: SJ3.2, U1.38 (PC7)
unnamed: SJ2.2, U1.39 (PC8)
unnamed: LED2.A, R5.2
unnamed: Q2.1 (G), U1.57 (PB5)
unnamed: Q3.1 (G), U1.58 (PB6)
unnamed: Q4.1 (G), U1.59 (PB7)
unnamed: Q5.1 (G), U1.33 (PB12)
unnamed: Q6.1 (G), U1.34 (PB13)
unnamed: Q7.1 (G), U1.35 (PB14)
unnamed: Q8.1 (G), U1.36 (PB15)
unnamed: R20.2, U1.28 (PB2)
unnamed: Q2.3 (D), R13.2, X3.5
unnamed: Q3.3 (D), R14.2, X3.9
unnamed: Q4.3 (D), R15.2, X3.6
unnamed: Q5.3 (D), R16.2, X3.2
unnamed: Q6.3 (D), R17.2, X3.4
unnamed: Q7.3 (D), R18.2, X3.3
unnamed: Q8.3 (D), R19.2, X3.1
NRST: C4.1, JP1.4, R2.1, U1.7 (NRST)
SWCLK: JP1.5, U1.49 (PA14)
SWDIO: JP1.6, U1.46 (PA13)
USB_DM: U1.44 (PA11), X2.2
USB_DP: U1.45 (PA12), X2.3
VCC: C1.1, C2.1, IC1.3 (IN), JP1.1, R13.1, R14.1, R15.1, R16.1, R17.1, R18.1, R19.1, X2.1, X3.7
VDD: BOOT0.3, C3.1, C5.1, C6.1, C9.1, C10.1, C11.1, C12.1, C13.1, C14.1, C15.1, C16.1, IC1.2 (OUT), IC1.TAB (OUT1), JP1.3, PA9BOOT.3, R2.2, R4.1, R5.1, SJ1.3, SJ2.3, SJ3.3, U1.1 (VBAT), U1.13 (VDDA), U1.19 (VDD_4), U1.32 (VDD_1), U1.48 (VDD_2), U1.64 (VDD_3)

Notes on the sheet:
1.0.0
HID2AMI Full: an awesome HID to Quadrature machine
PA2-> L "Deluxe Board" PA2-> H "Basic Board"
BOOT1

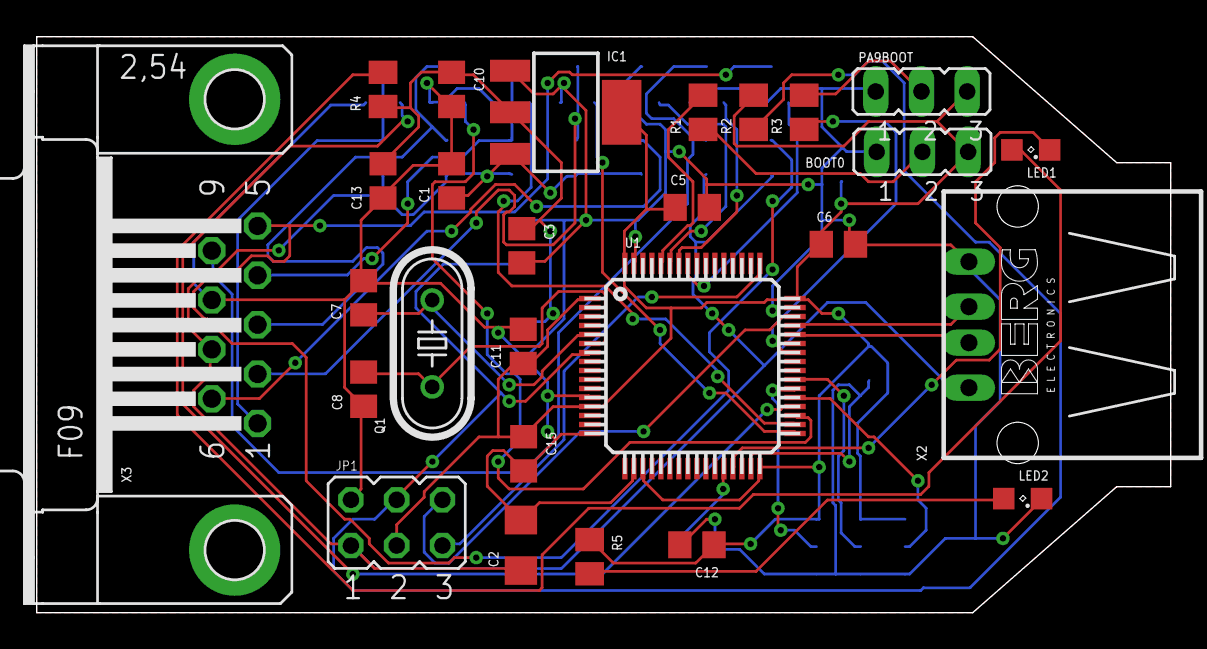
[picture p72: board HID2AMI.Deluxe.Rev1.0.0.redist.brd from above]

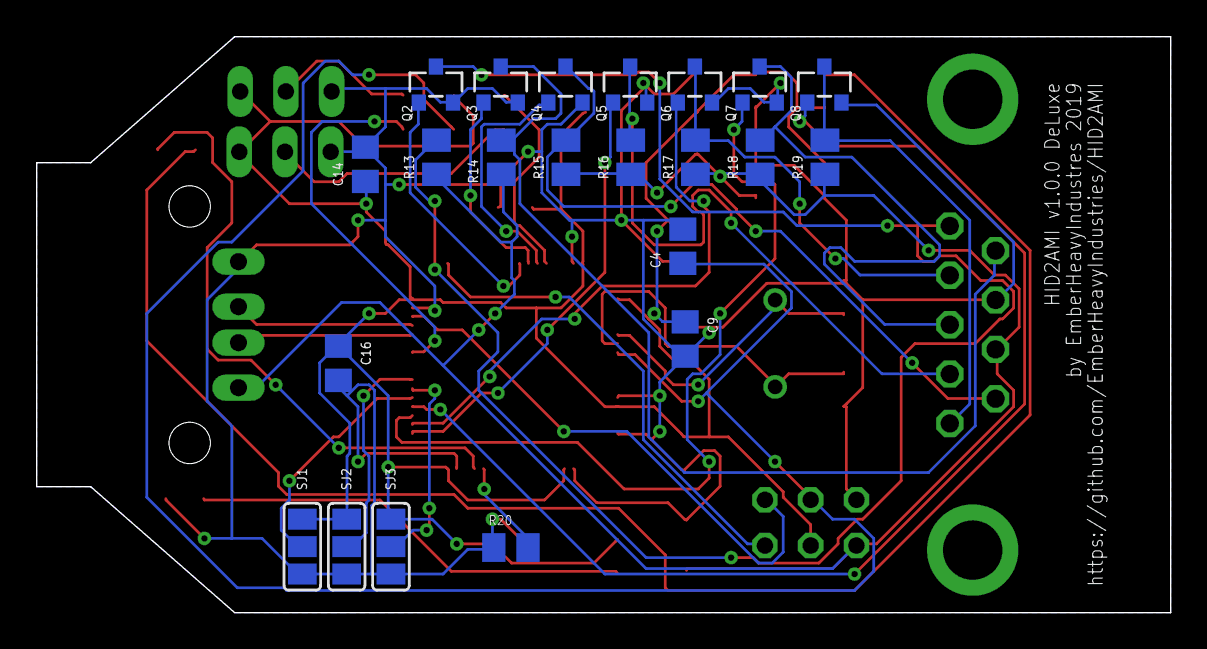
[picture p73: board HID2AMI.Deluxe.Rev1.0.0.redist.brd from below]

Board: 2 copper layers, 63.0 x 32.0 mm, 49 parts (22 on the bottom side), 35 nets.

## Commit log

2019-01-16 Create Schematics
2026-02-05 Update personality switch table in README.md
2026-02-05 Fix personality table header from W1 to SW1
    Updated personality table header to correct switch labeling.
2026-02-05 Revise personality table format in README
    Updated personality switch positions and notes format in the README.

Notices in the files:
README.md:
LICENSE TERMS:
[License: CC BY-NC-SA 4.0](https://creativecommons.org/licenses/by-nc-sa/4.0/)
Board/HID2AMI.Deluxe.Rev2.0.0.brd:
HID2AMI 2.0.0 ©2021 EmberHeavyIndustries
